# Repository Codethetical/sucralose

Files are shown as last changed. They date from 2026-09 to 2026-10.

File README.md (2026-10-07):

# Sucralose

Sucralose is a wireless, 42-key split keyboard built around Kailh PG1316S ultra-low-profile switches.
One reversible PCB serves both halves.

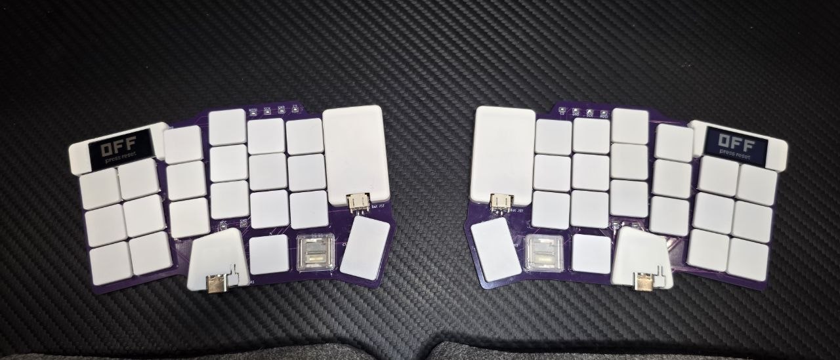
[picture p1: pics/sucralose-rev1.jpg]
Sucralose Rev. 1, both halves assembled


## Hardware

- **Switches:** [Kailh PG1316S](https://www.kailhswitch.com/uploads/15927/files/CPG1316S01D02-data-sheet.pdf),
  21 per half, on a 17 mm pitch to fit their smaller keycaps.
- **Controller:** Seeed XIAO nRF52840 Plus, running [ZMK](https://zmk.dev).
- **Display:** [nice!view](https://nicekeyboards.com/nice-view/), soldered flush to keep the stack low.
- **Power:** a LiPo pouch in a corner bay beside the key field, a JST-PH connector, and a side slide switch.
  An optional side reset button is also supported.
- **PCB:** 1 mm thick, so the full stack stays in ultra-low-profile range.

## Design

- **Layout:** the column splay is inspired by [chalk](https://github.com/maurzo/chalk).
  The 1.5u outer thumb key comes from the [Corne](https://github.com/foostan/crkbd).
- **Reversible:** each half uses the same board, flipped.
  - The XIAO footprint puts a land on both copper layers at every pin.
    Each layer carries the net that pin needs when the module is mounted on that side.
  - The nice!view header can't do that because its pins are plated through-holes.
    Four solder jumpers per side select its pin order instead.
- **Serviceable switches:** the PG1316S contacts sit under the switch body.
  The custom footprint uses plated through-holes so each joint can be reflowed from the underside.

## Custom Footprints

These live in `lib/footprints.pretty/`. The files ending in `_sucralose` were drawn for this board.

- **PG1316S:** a reversible footprint with plated through-holes and locating-pin holes.
  It builds on [mikefive](https://github.com/mikeholscher/zmk-config-mikefive)'s footprints and
  [marbastlib](https://github.com/ebastler/marbastlib)'s.
- **XIAO nRF52840 Plus:** a reversible version of Seeed's official single-sided footprint.
- **nice!view:** a dual-sided header, plus chevron solder jumpers for net selection.
- **Alps SSSS811101 power switch:** front and back versions, checked against
  [ceoloide's footprints](https://github.com/ceoloide/ergogen-footprints).
- **Other parts:** a reversible B3U reset button and SOD-123 diodes.

## Case

`case/out/` has STL files for the partial covers: a battery cover and battery plate, left and right XIAO covers, and a screen cover.
It also has left and right reference DXFs showing the outline, keycap clearances, and M1 screw holes.

## Firmware

This repo is also the [ZMK module](https://zmk.dev/docs/features/modules) for the board: `firmware/` holds the
`sucralose_left` / `sucralose_right` shield. See [`firmware/README.md`](firmware/README.md) for how to build it.

## License

Sucralose is released under the [MIT License](LICENSE).

The key switch layout is the exception. To the extent it is unchanged from [chalk](https://github.com/maurzo/chalk) by maurzo,
that layout stays under chalk's [CC BY-NC-SA 4.0](https://creativecommons.org/licenses/by-nc-sa/4.0/) license.
Third-party files in `reference/` and the footprints derived from upstream libraries also keep their own licenses.

## Credits

- **Corne:** [foostan/crkbd](https://github.com/foostan/crkbd), CC-BY-4.0.
- **Key switch layout:** [maurzo/chalk](https://github.com/maurzo/chalk) by maurzo, CC-BY-NC-SA-4.0.
- **PG1316S footprints:** [mikeholscher/zmk-config-mikefive](https://github.com/mikeholscher/zmk-config-mikefive)
  and [ebastler/marbastlib](https://github.com/ebastler/marbastlib), CERN-OHL-P.
- **PG1316M footprint and 3D model:** [dennisleexyz/libmodulo](https://github.com/dennisleexyz/libmodulo), GPL-3.0.

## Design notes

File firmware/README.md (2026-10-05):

# Sucralose firmware (ZMK module)

This repo is a [ZMK module](https://zmk.dev/docs/features/modules): `zephyr/module.yml` at the
repo root points ZMK at `firmware/`, which holds the `sucralose_left` / `sucralose_right` shield.

- Controller: Seeed XIAO nRF52840 Plus or Sense Plus, built as `seeeduino_xiao_ble`
  (see `docs/PINOUT.md` for why not `xiao_ble_sense`)
- Display: nice!view on both halves
- ZMK: v0.3

## Using it

In your zmk-config's `config/west.yml`, add this repo next to ZMK:

```yaml
    - name: sucralose
      remote: codethetical   # url-base: https://github.com/Codethetical
      revision: main
```

and in `build.yaml`:

```yaml
include:
  - board: seeeduino_xiao_ble
    shield: sucralose_left nice_view
  - board: seeeduino_xiao_ble
    shield: sucralose_right nice_view
```

`nice_view` must come after `sucralose_*`: the shield defines the display bus that `nice_view`
attaches to. There is no `nice_view_adapter`; the display is wired straight to the XIAO.

The left half is the central and advertises as "Sucralose". The default keymap is a 6-column
Corne layout; RESET and BOOT on the raise layer replace the XIAO's button.

## Pins

| Function | XIAO | nRF52840 |
|---|---|---|
| COL0..COL5 | D0 D1 D2 D3 D10 D5 | P0.02 P0.03 P0.28 P0.29 P1.15 P0.05 |
| ROW0..ROW3 | D6..D9 | P1.11..P1.14 |
| Display MOSI / SCK / CS | D4 / D11 / D12 | P0.04 / P0.15 / P0.19 (SPIM3) |

Both XIAO lands carry the same nets, so both halves use the same pins; the right half lists the
columns in reverse because its board is flipped.

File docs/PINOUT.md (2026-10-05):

# XIAO nRF52840 Plus pin assignment

## Where these pin numbers come from

ZMK has no board definition for the **Plus** -- only `seeed/xiao_ble` for the
standard XIAO nRF52840. The Plus keeps the standard 14-pin layout and adds nine
castellated pins, so the mapping was resolved from primary sources and
cross-checked, never from the wiki pinout image (which is disputed -- see below).

| Source | What it establishes |
|---|---|
| Zephyr `boards/seeed/xiao_ble/seeed_xiao_connector.dtsi` | `xiao_d` nexus: D0..D10 -> P0.02 P0.03 P0.28 P0.29 P0.04 P0.05 P1.11 P1.12 P1.13 P1.14 P1.15. ZMK inherits this. |
| Seeed `XIAO_Series_SCH_Symbols` symbol `XIAO-nRF52840_Plus_SMD` | Footprint pad number -> pin name: pads 1..11 = D0..D10, 12=3V3, 13=GND, 14=VBUS, pads 15..23 = D11..D19. |
| Seeed Plus KiCad PCB, header footprint `U4` | Pad -> net. Pads 1..11 match the Zephyr nexus exactly; pads 15..23 give D11..D19. |
| `reference/chalk/reversible.kicad_pcb` | A working board. Its XIAO pads 1..14 are netted P0..P10 / VCC33 / GND / VCC5, agreeing with the symbol on all 14 shared pads. |

Two independent chains agree on every pin used here.

## Full Plus pin table

| Pad | Name | Port | Used for |
|---|---|---|---|
| 1 | D0 | P0.02 | COL0 |
| 2 | D1 | P0.03 | COL1 |
| 3 | D2 | P0.28 | COL2 |
| 4 | D3 | P0.29 | COL3 |
| 5 | D4 | P0.04 | display MOSI |
| 6 | D5 | P0.05 | COL5 |
| 7 | D6 | P1.11 | ROW0 |
| 8 | D7 | P1.12 | ROW1 |
| 9 | D8 | P1.13 | ROW2 |
| 10 | D9 | P1.14 | ROW3 |
| 11 | D10 | P1.15 | COL4 |
| 12 | 3V3 | - | display VCC |
| 13 | GND | - | GND |
| 14 | VBUS | - | (unused) |
| 15 | D11 | P0.15 | display SCK |
| 16 | D12 | P0.19 | display CS |
| 17 | D13 | P1.01 | free |
| 18 | D14 | P0.09 | free (NFC) |
| 19 | D15 | P0.10 | free (NFC) |
| 20 | D16 | P0.31 | free (battery sense) |
| 21 | D17 | P1.03 | free (disputed) |
| 22 | D18 | P1.05 | free (disputed) |
| 23 | D19 | P1.07 | free (disputed) |

## Pins deliberately avoided

- **D14 = P0.09, D15 = P0.10** are NFC pins by default. Usable as GPIO only with
  `CONFIG_NFCT_PINS_AS_GPIOS`.
- **D16 = P0.31** is AIN7/BAT. ZMK's `xiao_ble` board reads battery voltage on
  the ADC, so leave it alone.
- **D17/D18/D19 = P1.03/P1.05/P1.07.** Seeed's published Plus pinout image is
  reported wrong for exactly these: one user found "1.03 and 1.07 are SWAPPED"
  and confirmed it against the KiCad files; another found that blinking D19 lit
  the pad silkscreened D17. Seeed acknowledged an inconsistency. Nothing here
  depends on them.

The whole design fits in **D0..D12**, all corroborated by two independent
sources, leaving D13..D19 free.

## ZMK kscan

`diode-direction = "col2row"`: current flows column -> switch -> diode anode ->
cathode -> row, which is how the netlist is wired (switch pad 1 = column,
switch pad 2 = diode pad 2, diode pad 1 = row).

```dts
kscan0: kscan {
    compatible = "zmk,kscan-gpio-matrix";
    wakeup-source;
    diode-direction = "col2row";

    col-gpios
        = <&xiao_d 0 GPIO_ACTIVE_HIGH>   /* COL0  D0  P0.02 */
        , <&xiao_d 1 GPIO_ACTIVE_HIGH>   /* COL1  D1  P0.03 */
        , <&xiao_d 2 GPIO_ACTIVE_HIGH>   /* COL2  D2  P0.28 */
        , <&xiao_d 3 GPIO_ACTIVE_HIGH>   /* COL3  D3  P0.29 */
        , <&xiao_d 10 GPIO_ACTIVE_HIGH>  /* COL4  D10 P1.15 */
        , <&xiao_d 5 GPIO_ACTIVE_HIGH>   /* COL5  D5  P0.05 */
        ;

    row-gpios
        = <&xiao_d 6 (GPIO_ACTIVE_HIGH | GPIO_PULL_DOWN)>  /* ROW0 D6 P1.11 */
        , <&xiao_d 7 (GPIO_ACTIVE_HIGH | GPIO_PULL_DOWN)>  /* ROW1 D7 P1.12 */
        , <&xiao_d 8 (GPIO_ACTIVE_HIGH | GPIO_PULL_DOWN)>  /* ROW2 D8 P1.13 */
        , <&xiao_d 9 (GPIO_ACTIVE_HIGH | GPIO_PULL_DOWN)>  /* ROW3 D9 P1.14 */
        ;
};
```

The `xiao_d` nexus only defines D0..D10. Display lines (as shipped in
`firmware/boards/shields/sucralose/boards/seeeduino_xiao_ble.overlay`):

```dts
&pinctrl {
    spi3_default: spi3_default {
        group1 {
            psels = <NRF_PSEL(SPIM_SCK,  0, 15)>,   /* SCK  D11 P0.15 */
                    <NRF_PSEL(SPIM_MOSI, 0, 4)>;    /* MOSI D4  P0.04 */
        };
    };
    /* spi3_sleep: same pins, low-power-enable */
};
nice_view_spi: &spi3 {
    compatible = "nordic,nrf-spim";
    pinctrl-0 = <&spi3_default>;
    pinctrl-1 = <&spi3_sleep>;
    pinctrl-names = "default", "sleep";
    cs-gpios = <&gpio0 19 GPIO_ACTIVE_HIGH>;         /* CS   D12 P0.19 */
};
```

SCK, MOSI and CS all sit on pins the nRF52840 spec rates for a fast clock
(table below). No MISO: the LS0xx is write-only.

- **CS is active high.** The LS0xx selects on a high SCS, and ZMK's own
  nice!view adapters use `GPIO_ACTIVE_HIGH`. Active low leaves the panel blank.
- **Why SPIM3.** On the `seeeduino_xiao_ble` board ZMK builds for, spi2 and
  i2c0 are defined but disabled, so SPIM0..3 are all free. SPIM0 is avoided
  because it shares its peripheral with TWIM0, the I2C bus the Sense's
  on-module IMU uses (P0.07/P0.27); SPIM3 keeps that open.
- **Board choice.** Build as `seeeduino_xiao_ble`, not Zephyr's `xiao_ble_sense`.
  The latter enables i2c1 on D4/D5 (display MOSI, COL5), spi2 on D8..D10
  (ROW2, ROW3, COL4) and uart0 on D6/D7 (ROW0, ROW1), and has no ZMK battery
  or USB/BLE config. The Sense's IMU and microphone sit on internal pins, so
  this board choice does not rule them out.

## Matrix

21 keys: 6 columns x 3 rows, plus 3 thumbs on ROW3.

| | COL0 outer | COL1 pinky | COL2 ring | COL3 middle | COL4 index | COL5 inner |
|---|---|---|---|---|---|---|
| ROW0 | SW13 | SW16 | SW3 | SW14 | SW9 | SW6 |
| ROW1 | SW5 | SW20 | SW7 | SW10 | SW12 | SW11 |
| ROW2 | SW19 | SW1 | SW8 | SW18 | SW2 | SW15 |
| ROW3 | - | - | - | SW4 | SW21 | SW17 |

## Display SPI pins: which GPIOs can carry a 1 MHz clock

Source: nRF52840 Product Specification v1.11, section 7 "aQFN73 ball
assignments" (pages 926–933 of the DigiKey PDF). Each GPIO is tagged either
plain "General purpose I/O" or "Standard drive, low frequency I/O only".
Nordic defines low frequency as up to 10 kHz (note on the same table;
DevZone case 232044 confirms: the tag marks pins near the radio that can
desense it when driven fast). The nice!view runs at `spi-max-frequency =
<1000000>` (ZMK `shields/nice_view/nice_view.overlay`), 100x over that.

| Pad | Name | Port | Spec tag | 1 MHz SPI |
|---|---|---|---|---|
| 1 | D0 | P0.02 | low frequency only | no |
| 2 | D1 | P0.03 | low frequency only | no |
| 3 | D2 | P0.28 | low frequency only | no |
| 4 | D3 | P0.29 | low frequency only | no |
| 5 | D4 | P0.04 | general purpose | **yes** |
| 6 | D5 | P0.05 | general purpose | **yes** |
| 7 | D6 | P1.11 | low frequency only | no |
| 8 | D7 | P1.12 | low frequency only | no |
| 9 | D8 | P1.13 | low frequency only | no |
| 10 | D9 | P1.14 | low frequency only | no |
| 11 | D10 | P1.15 | low frequency only | no |
| 15 | D11 | P0.15 | general purpose | **yes** |
| 16 | D12 | P0.19 | general purpose (QSPI/SCK on the module) | **yes** |
| 17 | D13 | P1.01 | low frequency only | no |
| 18 | D14 | P0.09 | low frequency only, NFC | no |
| 19 | D15 | P0.10 | low frequency only, NFC | no |
| 20 | D16 | P0.31 | low frequency only, battery sense | no |
| 21 | D17 | P1.03 | low frequency only | no |
| 22 | D18 | P1.05 | low frequency only | no |
| 23 | D19 | P1.07 | low frequency only | no |

Consequences:

- The current SCK/CS on D11/D12 (pads 15/16) are the right *electrical*
  choice: they are two of only four pins on the whole module rated for a
  fast clock. They are also the two hardest pads to route.
- Of the Plus-only pins, none is rated for SPI. Moving SCK or CS to
  D13–D19 to ease routing would put the display clock on a radio-adjacent
  pin the spec limits to 10 kHz. Seeed's own board uses P1.13/P1.15
  (low-frequency pins) for its stock `spi2`, so it works in practice, but
  it is out of spec with the radio on.
- The only in-spec fast pins on the **non-Plus** XIAO edge are D4 and D5
  (P0.04/P0.05). A design that must run on the original XIAO nRF52840 has
  exactly two SPI-capable pins, which is SCK + MOSI with CS on any GPIO
  (CS is static, no frequency limit). That leaves 9 pins for the matrix:
  a 6x4 needs 10. So the non-Plus board cannot carry this matrix plus an
  in-spec display; the Plus is required, and D11/D12 stay.
- MOSI was on D10 (P1.15), a low-frequency pin, carrying data at the same
  1 MHz as SCK. Decided 2026-09-19: MOSI moved to D4 (P0.04, fast pin);
  COL4 took D10. Matrix scanning is far below 10 kHz, so a column on a
  low-frequency pin is in spec. All three display lines (MOSI D4, SCK D11,
  CS D12) are now on the four fast pins.

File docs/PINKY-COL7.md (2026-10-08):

# Pinky Column 7 (Branch `pinky-col7`): Status and Handoff

Last updated 2026-10-07 (UTC). Head `1fa790a`. Main is untouched.

## What Exists

- **Footprint:** `lib/footprints.pretty/SW_PG1316M_th_reversible_sucralose.kicad_mod` (on main, GPL-3.0, derived from dennisleexyz/libmodulo `SW_PG1316M` @5dbcd9b). The datasheet's 1.55x2 mm terminal lands at (+/-2.5, 0.7) are PTH with a 1.0 mm drill. The MP pads at (+/-6.35, +/-3.95) are duplicated F/B. Locating NPTHs at (+/-5.8, 0) are both 1.25 mm so either face fits. Courtyard is 16x10.3 mm (F-row keycap); the case guard is +0.5 mm, about 17.0x11.3 mm.
- **Datasheet and model:** `docs/PG1316M-datasheet.pdf`, `lib/3d/PG1316M.STEP`.
- **Strip:** 4x PG1316M, portrait (rot 9-90 = -81), at u=-17.5 in COL0's frame (origin = SW5 `C0 R1`, rot 9 deg), 17 mm pitch, centred in the strip.
  - Refs top to bottom: C6 R3 (D22, ROW3), C6 R0 (D23, ROW0), C6 R1 (D24, ROW1), C6 R2 (D25, ROW2).
  - Switch-to-diode nets: `pinky7_extra/top/home/bottom`.
  - COL6 goes to XIAO pad 17 (D13 = P1.01) on both copies. C6 R3 uses the free ROW3/COL6 matrix slot.
- **Breakaway:**
  - Five tabs of 0.6 mm NPTH perforations with a 0.35 mm web, plus 1.0 mm slots (the JLCPCB minimum NP slot). The fifth (MB5, 5 holes, solid span 5.46 mm) sits at the C6 R0/R1 key boundary and splits the long middle slot.
  - The main-side slot wall lies on the Rev. 1 COL0 edge, so the snapped board keeps the Rev. 1 outline and corners and existing covers fit.
  - The strip spans the full board height, and its outer corners copy the main corner rounds. Inner corners now hug the main board's corner rounds: a 1.0 mm-gap arc concentric with each main corner, filleted R0.5 into the strip's top/bottom edge (`scripts/hug_pinky_col7_corners.py`, run after `gen_pinky_col7.py`).
  - Middle tabs carry the nets (3+3 holes around a copper channel). Dead-end stubs remain after a snap; file the edge.
- **DRC:** copper clean. The unconnected set matches main (7 display/battery ring pairs). Only new items are 8 `lib_footprint_issues` local-override warnings.

## Open Items

1. **ROW3 trace:** C6 R3's ROW3 trace runs diagonally across the C0 R0/R1 area on the top side. It's cosmetic. Jahn was offered a reroute along the edge or under the display; no decision yet.
2. **Firmware not updated:**
   - 7 columns: add COL6 = `&xiao_d 13` to the left/right overlays (the right is mirrored, so COL6 goes first) and `col-offset` = 7.
   - Matrix transform and keymap need the C6 positions (R0-R3).
3. **Keycap gap:** C6 keycaps sit about 4.3 mm from C0's; main columns are about 1 mm apart. Closing it pushes the switches into the slots.
4. **Not done yet:** cover/case model updates, a JLCPCB order check (confirm mouse bites and slots in the Gerber preview), and a physical snap test.

## How It Was Built (Scripts Are Gitignored, Local Only)

- `scripts/gen_pinky_col7.py`: start from `git show main:pcb/sucralose.kicad_pcb`. It places the switches, diodes, and mouse bites, rewrites the COL0 edge, and adds pad-17 COL6. It snaps new outline ends to existing ones and drops zero-length lines (KiCad `invalid_outline` otherwise).
- `scripts/route/route_col7.py`: run `extract_geom.py` first. It freezes existing copper, routes only the strip nets, and ties the diode back lands with vias. Takes about 1 minute.
- To verify: run DRC against `main` (`kicad-cli pcb drc`) and diff the category counts.

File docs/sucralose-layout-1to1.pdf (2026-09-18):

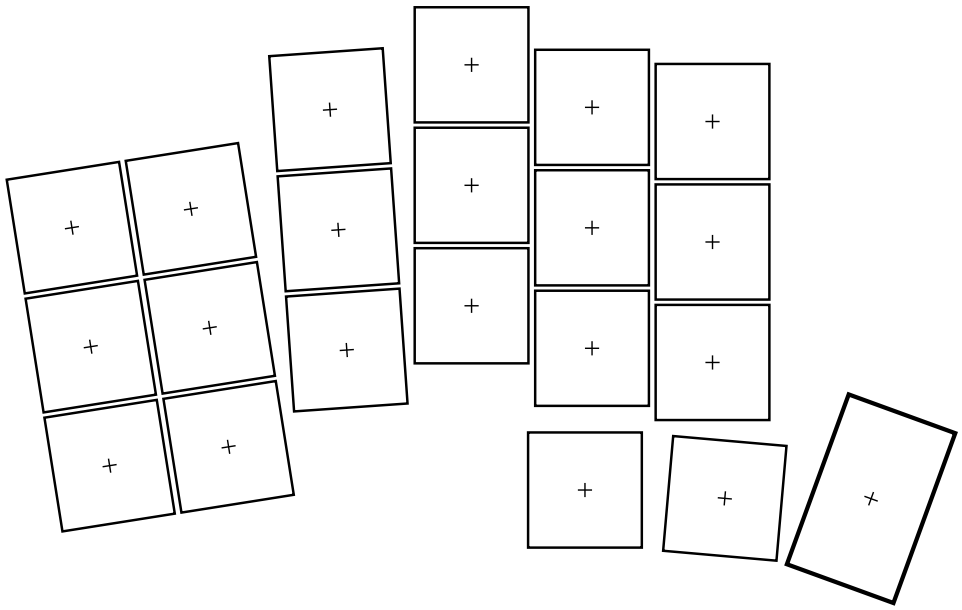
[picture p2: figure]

VERIFY SCALE FIRST: this ruler must measure exactly 100 mm. Print at 100%, scaling OFF / "Actual size".

SUCRALOSE · LEFT half · chalk splay, 17 mm pitch · outer thumb 1.5u (25.5 x 16 mm), rotated +90 deg, raised 4.8 mm

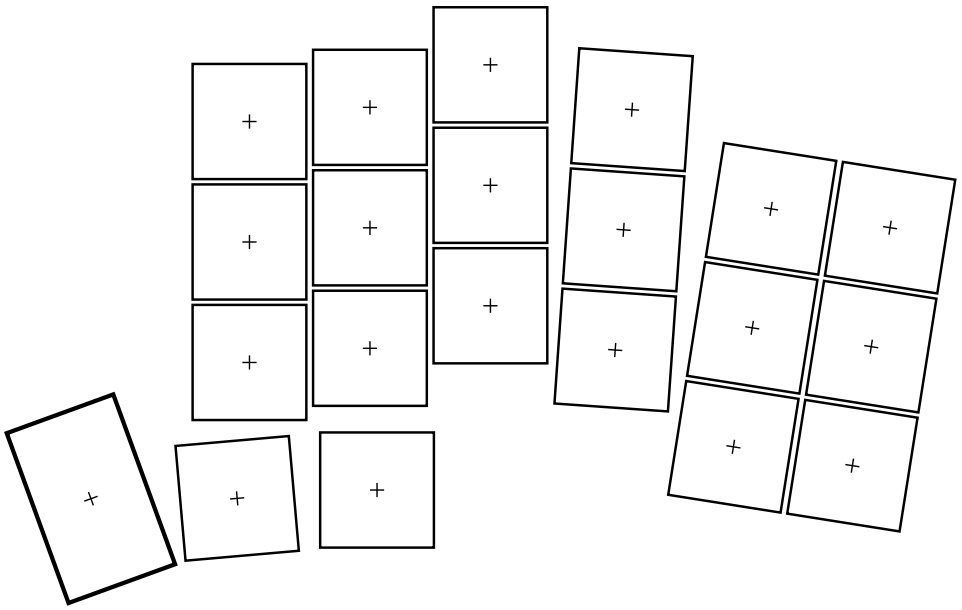
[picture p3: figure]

VERIFY SCALE FIRST: this ruler must measure exactly 100 mm. Print at 100%, scaling OFF / "Actual size".

SUCRALOSE · RIGHT half · chalk splay, 17 mm pitch · outer thumb 1.5u (25.5 x 16 mm), rotated +90 deg, raised 4.8 mm

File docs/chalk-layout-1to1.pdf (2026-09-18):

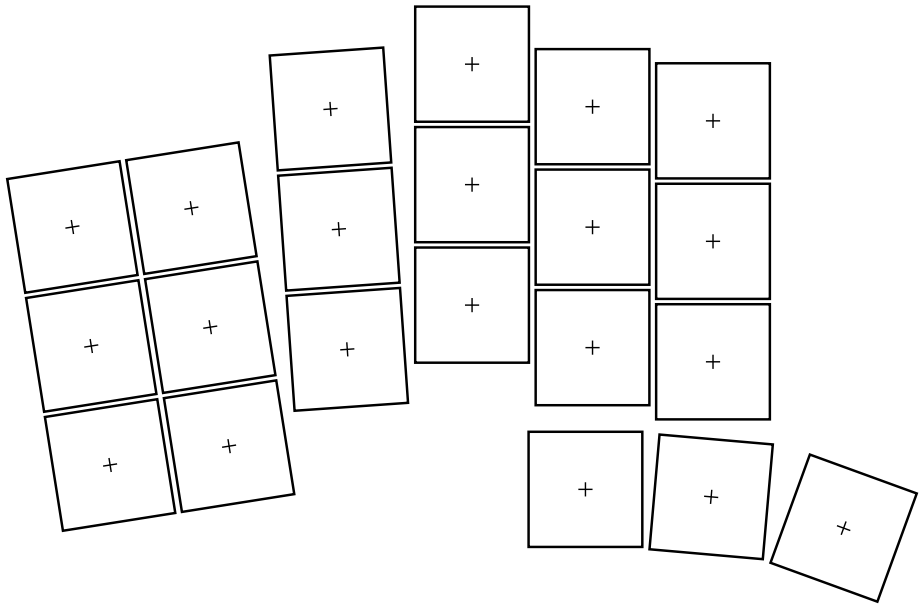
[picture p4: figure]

VERIFY SCALE FIRST: this ruler must measure exactly 100 mm. Print at 100%, scaling OFF / "Actual size".

LEFT half · chalk layout, 17 mm pitch, PG1316S 1u caps 16.05 x 16.25 mm · geometry measured from maurzo/chalk (CC-BY-NC-SA-4.0)

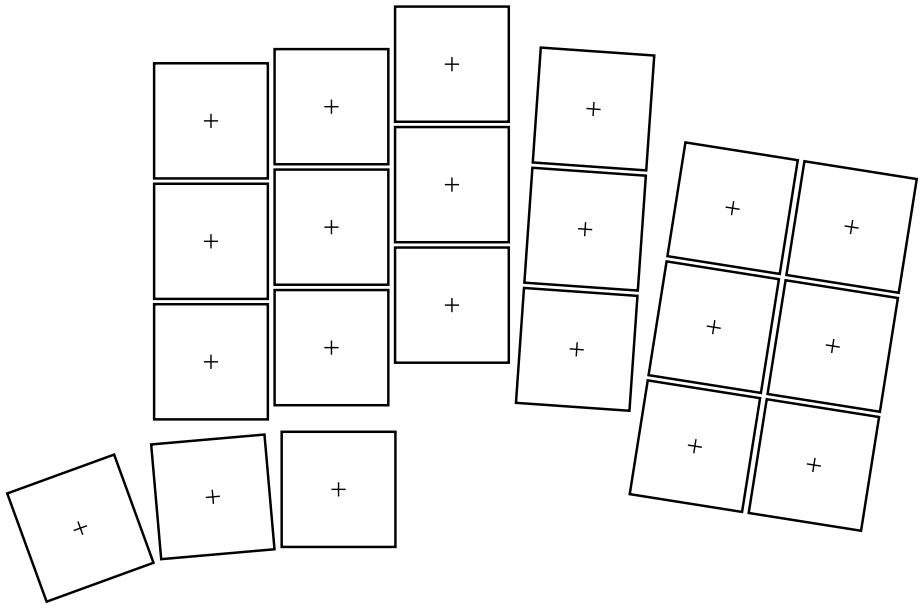
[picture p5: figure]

VERIFY SCALE FIRST: this ruler must measure exactly 100 mm. Print at 100%, scaling OFF / "Actual size".

RIGHT half · chalk layout, 17 mm pitch, PG1316S 1u caps 16.05 x 16.25 mm · geometry measured from maurzo/chalk (CC-BY-NC-SA-4.0)

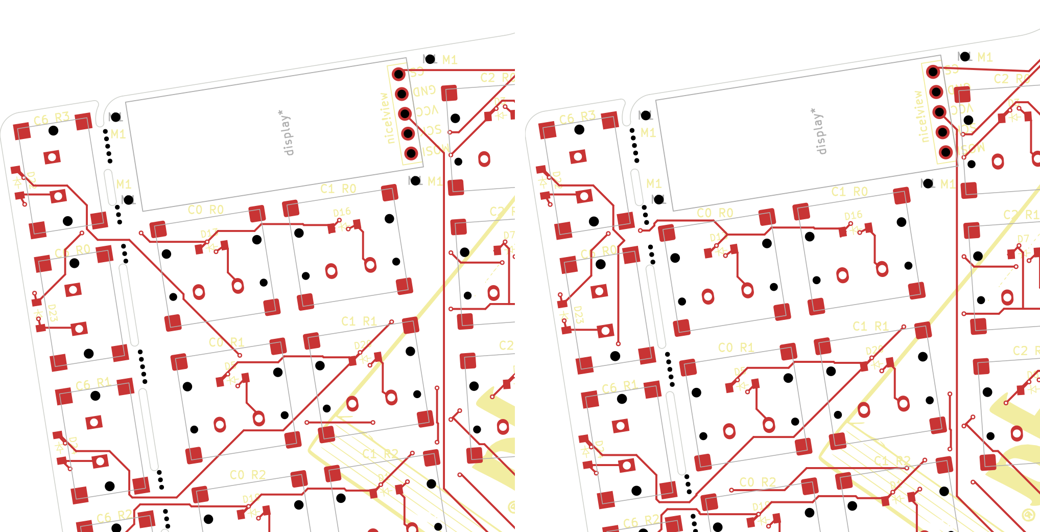
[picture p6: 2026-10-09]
pics/sucralose-display-inboard-compare.png

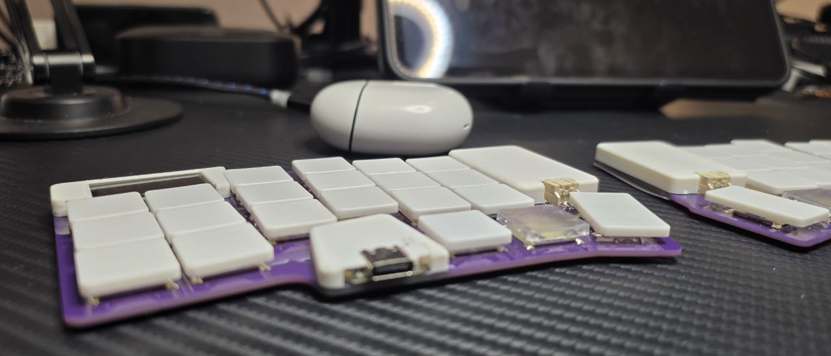
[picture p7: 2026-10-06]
pics/rev1-front-angled.jpg

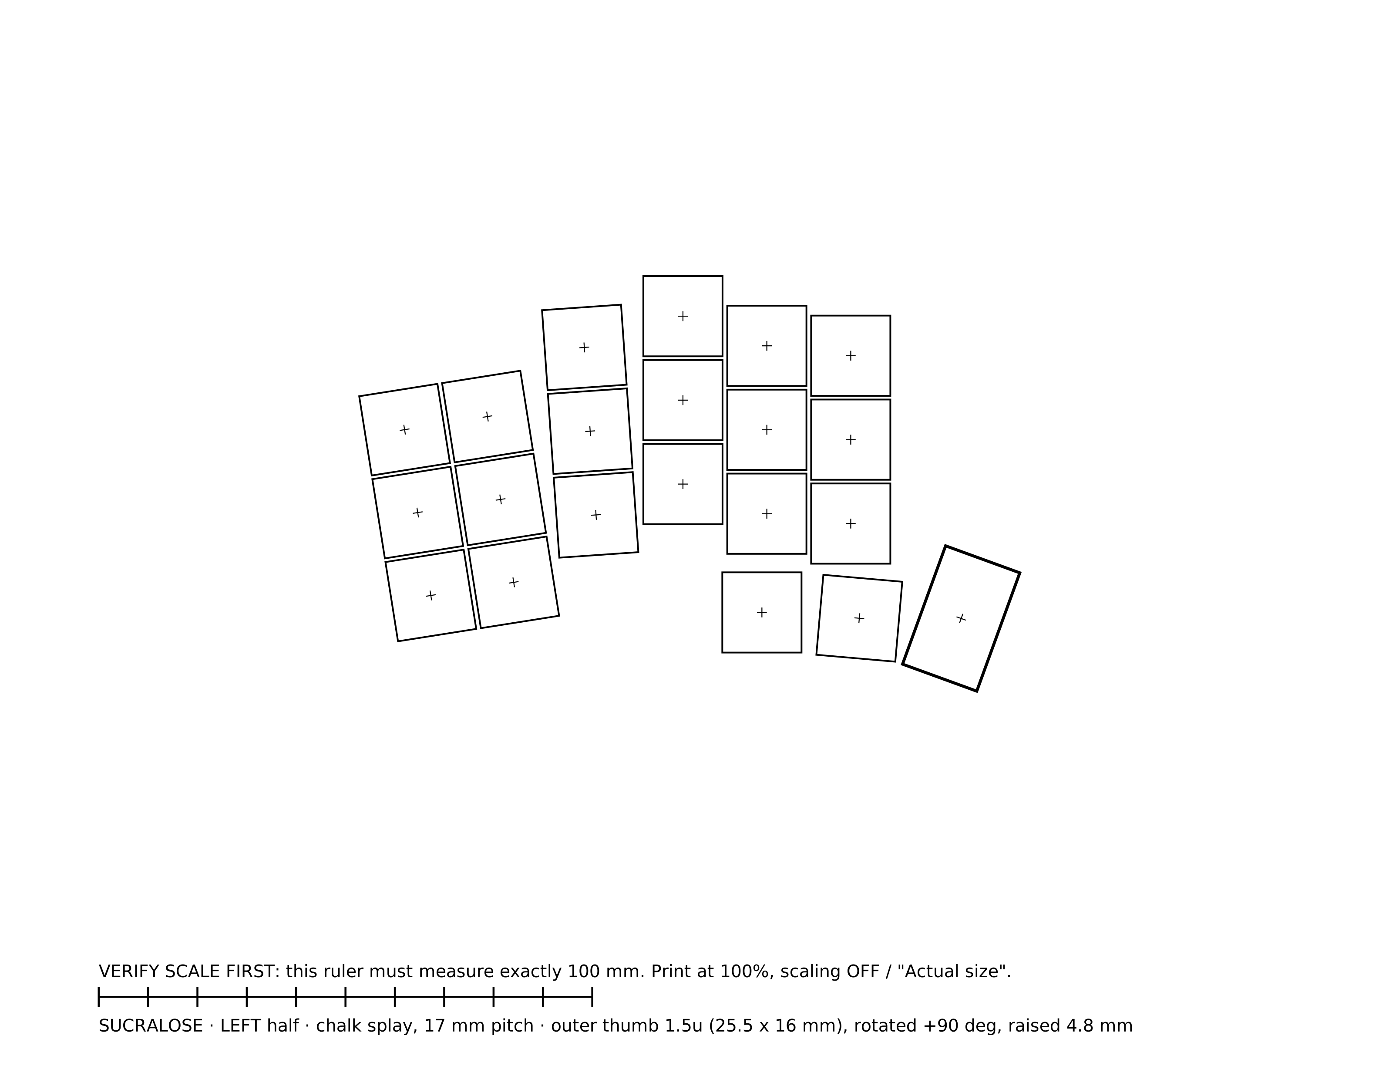
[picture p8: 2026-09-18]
docs/img/sucralose-layout-left.png

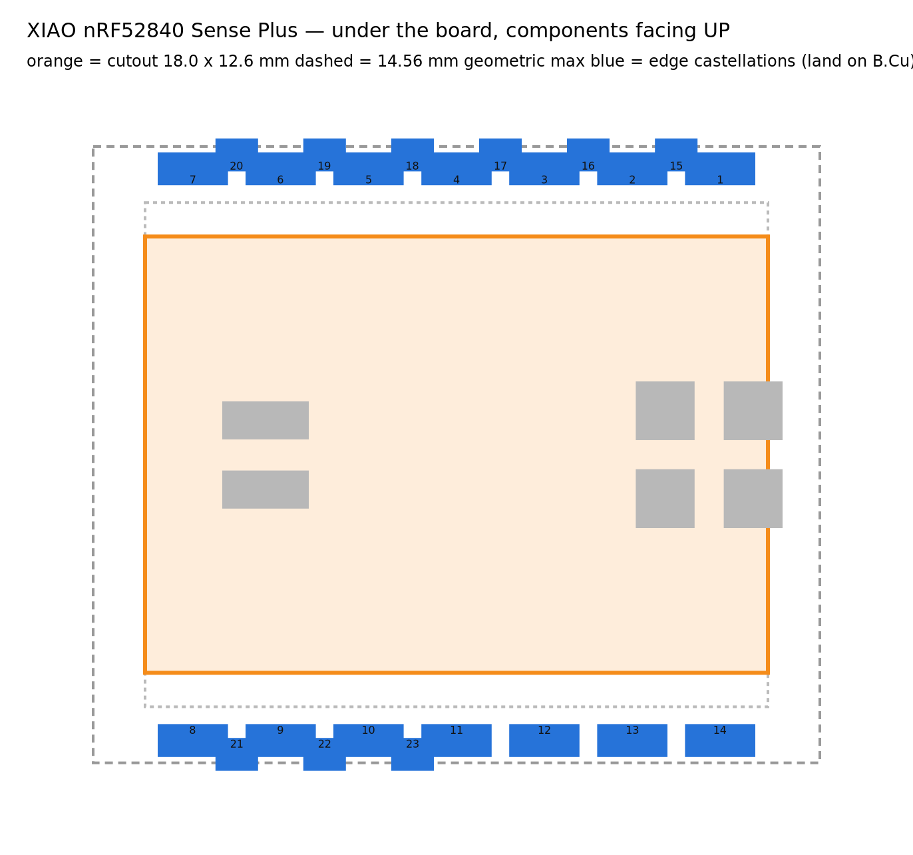
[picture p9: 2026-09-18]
docs/img/xiao-cutout.png

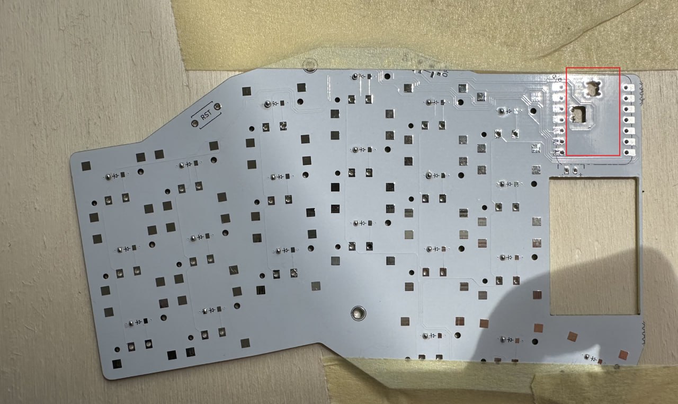
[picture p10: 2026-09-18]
docs/img/chalk-pcb-cutout-reference.jpg

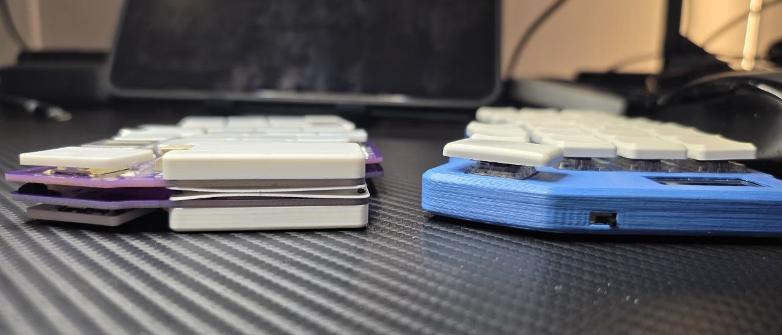
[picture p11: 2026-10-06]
pics/rev1-height-vs-cased-board.jpg

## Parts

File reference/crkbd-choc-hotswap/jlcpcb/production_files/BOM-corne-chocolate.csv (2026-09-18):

Comment | Designator | Footprint | LCSC
W25Q128JVSIQ | U4,rU4 | SOIC-8_5.23x5.23mm_P1.27mm | C113767
1k | R3,R6,rR3,rR6 | R_0402_1005Metric | C11702
TRS | J2,rJ2 | PJ-398A-5A_PJ-399B-6A | C128994
TPD4E05U06DQAR | U3,rU3 | USON-10_2.5x1.0mm_P0.5mm | C138714
RB521S30T1G | ZD1,rZD1 | D_SOD-523 | C145179
NCP1117LPST33T3G | U2,rU2 | SOT-223-3_TabPin2 | C146799
100n | C10,C12,C13,C14,C15,C3,C4,C7,C9,rC10,rC12,rC13,rC14,rC15,rC3,rC4,rC7,rC9 | C_0402_1005Metric | C1525
10u | C11,C6,rC11,rC6 | C_0402_1005Metric | C15525
27p | C1,C2,rC1,rC2 | C_0402_1005Metric | C1557
RP2040 | U1,rU1 | QFN-56-1EP_7x7mm_P0.4mm_EP3.2x3.2mm | C2040
1N4148WT | D1,rD1 | D_SOD-523 | C232841
10k | R7,R9,rR7,rR9 | R_0402_1005Metric | C25744
5.1k | R1,R2,rR1,rR2 | R_0402_1005Metric | C25905
5.6k | R8,rR8 | R_0402_1005Metric | C25908
TYPE-C-31-M-13C | J1,rJ1 | TYPE-C-31-M-13C | C2848620
27 | R4,R5,rR4,rR5 | R_0402_1005Metric | C2909343
TS-1088R-02026 | SMDSW1,SMDSW2,rSMDSW1,rSMDSW2 | TS-1088R-02026 | C455280
YS-SK6812MINI-E | EXLED1,EXLED2,LED1,LED10,LED11,LED12,LED13,LED14,LED15,LED16,LED17,LED18,LED19,LED2,LED20,LED21,LED3,LED4,LED5,LED6,LED7,LED8,LED9,rEXLED1,rEXLED2,rLED1,rLED10,rLED11,rLED12,rLED13,rLED14,rLED15,rLED16,rLED17,rLED18,rLED19,rLED2,rLED20,rLED21,rLED3,rLED4,rLED5,rLED6,rLED7,rLED8,rLED9 | YS-SK6812MINI-E | C5149201
1u | C16,C5,C8,rC16,rC5,rC8 | C_0402_1005Metric | C52923
RotaryEncoder_Switch | EXSW1,EXSW2,SW1,SW10,SW11,SW12,SW13,SW14,SW15,SW16,SW17,SW18,SW19,SW2,SW20,SW21,SW3,SW4,SW5,SW6,SW7,SW8,SW9,rEXSW1,rEXSW2,rSW1,rSW10,rSW11,rSW12,rSW13,rSW14,rSW15,rSW16,rSW17,rSW18,rSW19,rSW2,rSW20,rSW21,rSW3,rSW4,rSW5,rSW6,rSW7,rSW8,rSW9 | keyswitch_choc12_hotswap_1u_rotary_encoder_ec12 | C5333465
12MHz 18pF | Y1,rY1 | Crystal_SMD_3225-4Pin_3.2x2.5mm | C91749

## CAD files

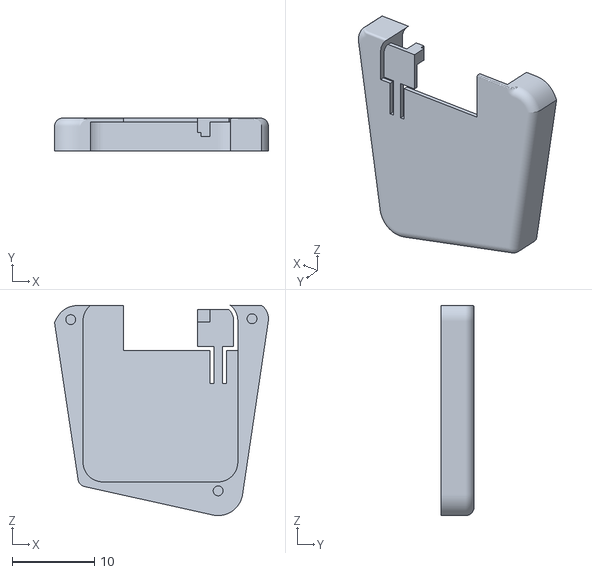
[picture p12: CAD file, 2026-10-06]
case/out/Sucralose L Xiao Cover Rev 4.stl
26.0 x 4.00 x 25.5

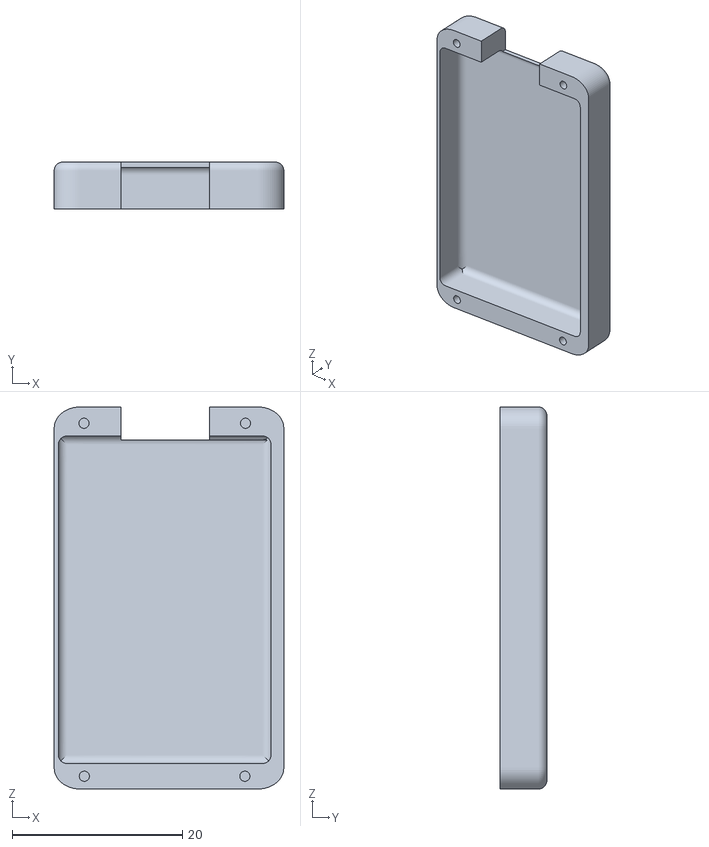
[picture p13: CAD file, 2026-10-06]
case/out/Sucralose L Battery Cover Rev 1.stl
27.0 x 5.50 x 44.9

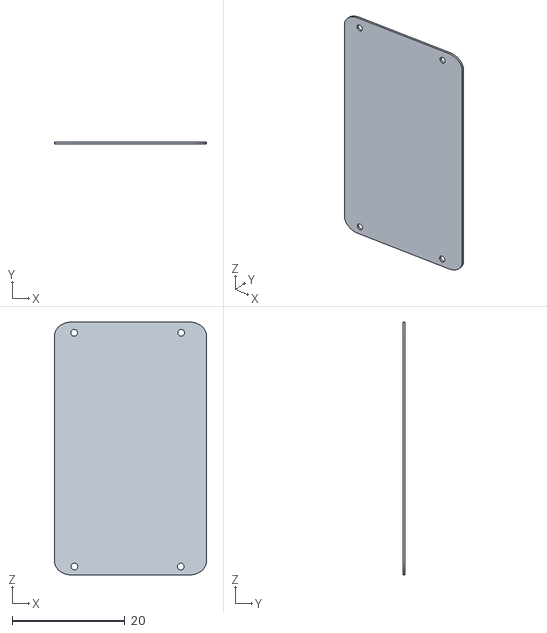
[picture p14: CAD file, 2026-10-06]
case/out/Sucralose L Battery Plate Rev 1.stl
27.0 x 0.4 x 44.9

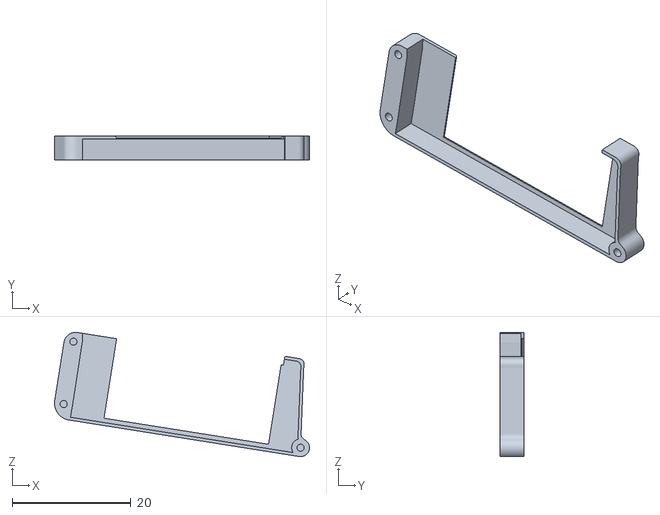
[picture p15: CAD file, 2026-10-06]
case/out/Sucralose L Screen Cover Rev 8.stl
42.9 x 4.00 x 20.9

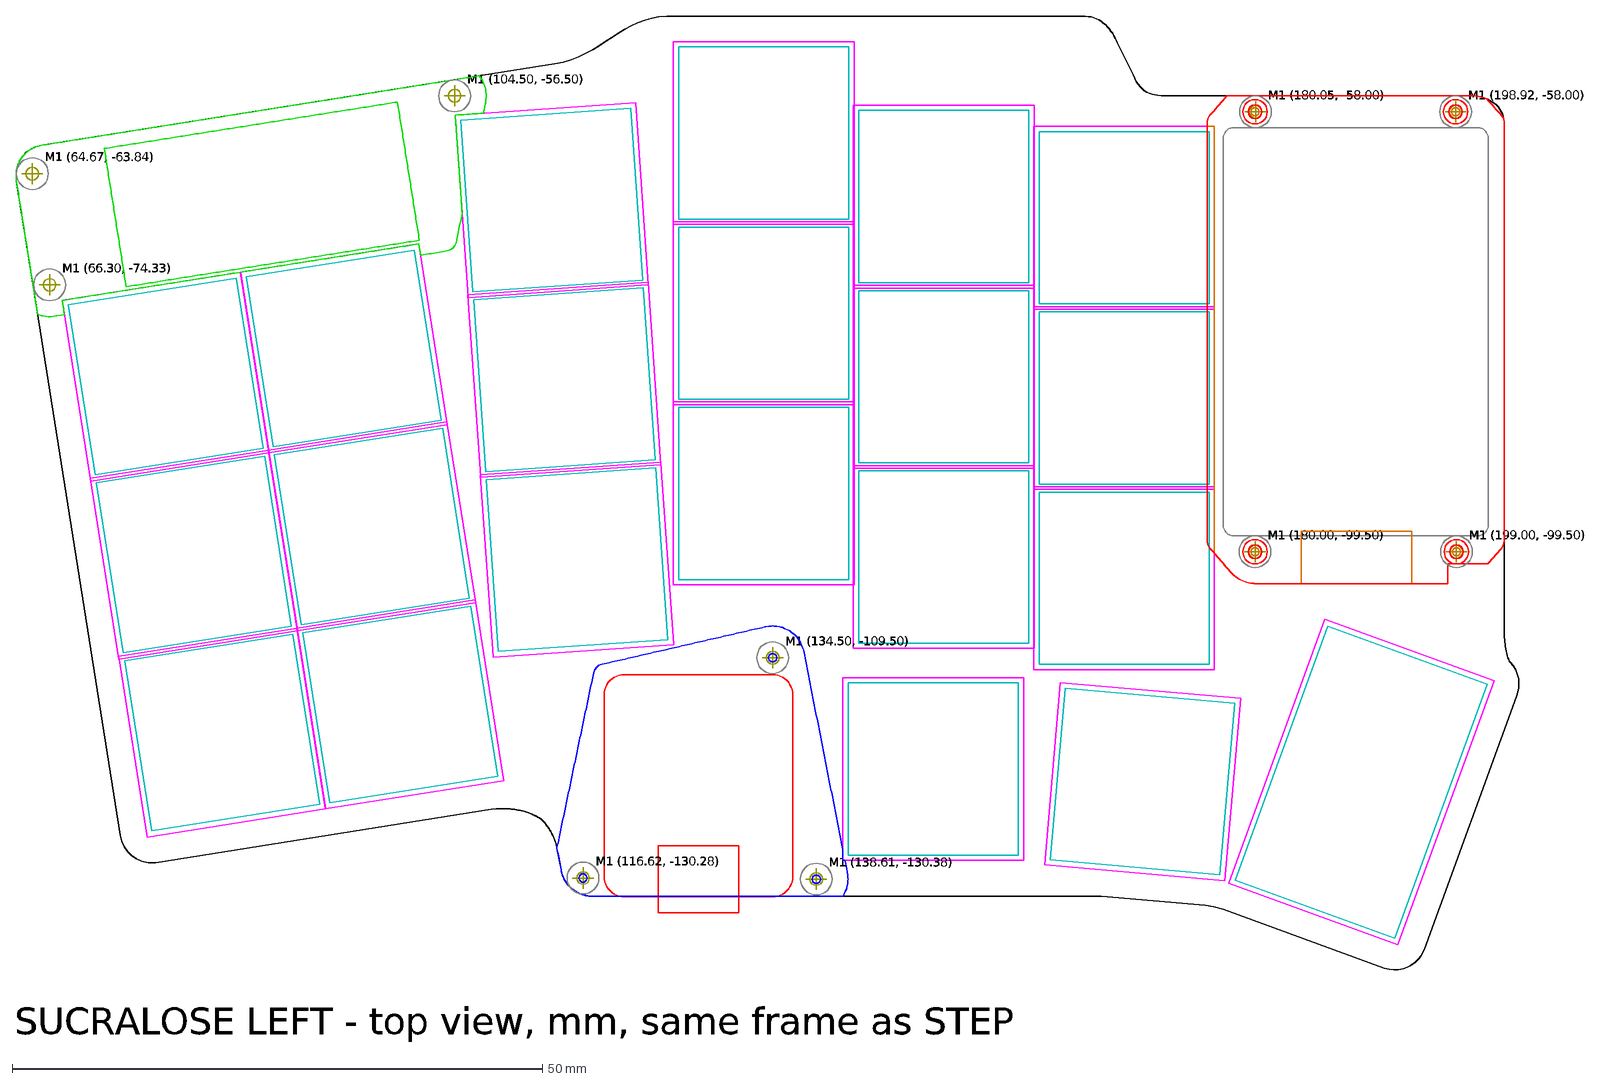
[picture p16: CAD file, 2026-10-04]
case/out/sucralose_reference_L.dxf
M1 (138.61, -130.38)
M1 (199.00, -99.50)
M1 (180.00, -99.50)
M1 (104.50, -56.50)
M1 (198.92, -58.00)
M1 (66.30, -74.33)
M1 (134.50, -109.50)
M1 (116.62, -130.28)
M1 (64.67, -63.84)
M1 (180.05, -58.00)
SUCRALOSE LEFT - top view, mm, same frame as STEP

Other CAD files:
case/out/Sucralose R Xiao Cover Rev 1.stl
case/out/sucralose_reference_R.dxf

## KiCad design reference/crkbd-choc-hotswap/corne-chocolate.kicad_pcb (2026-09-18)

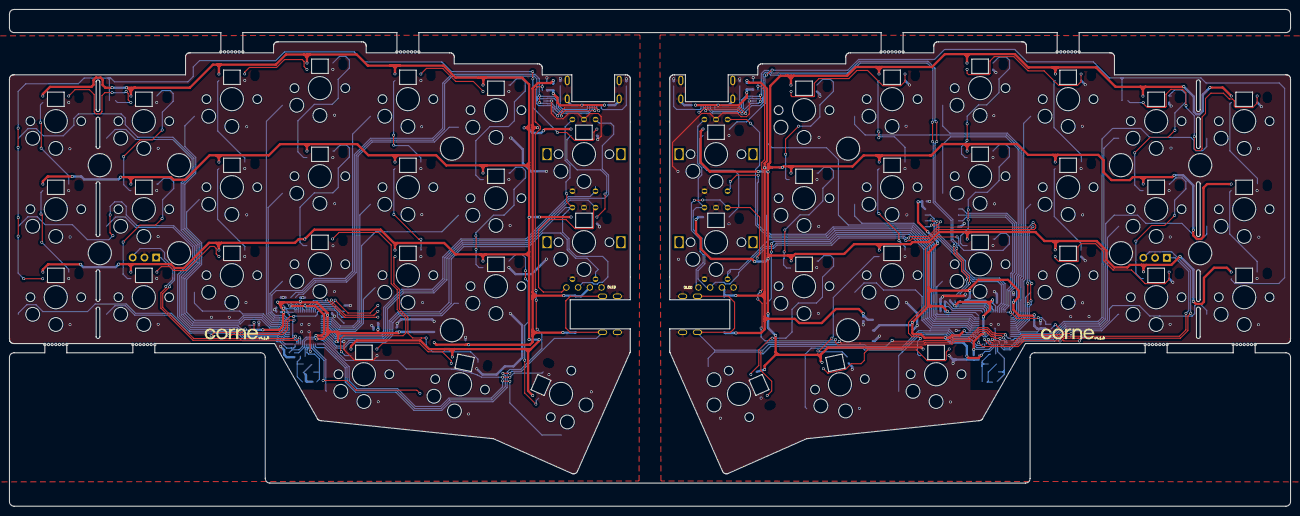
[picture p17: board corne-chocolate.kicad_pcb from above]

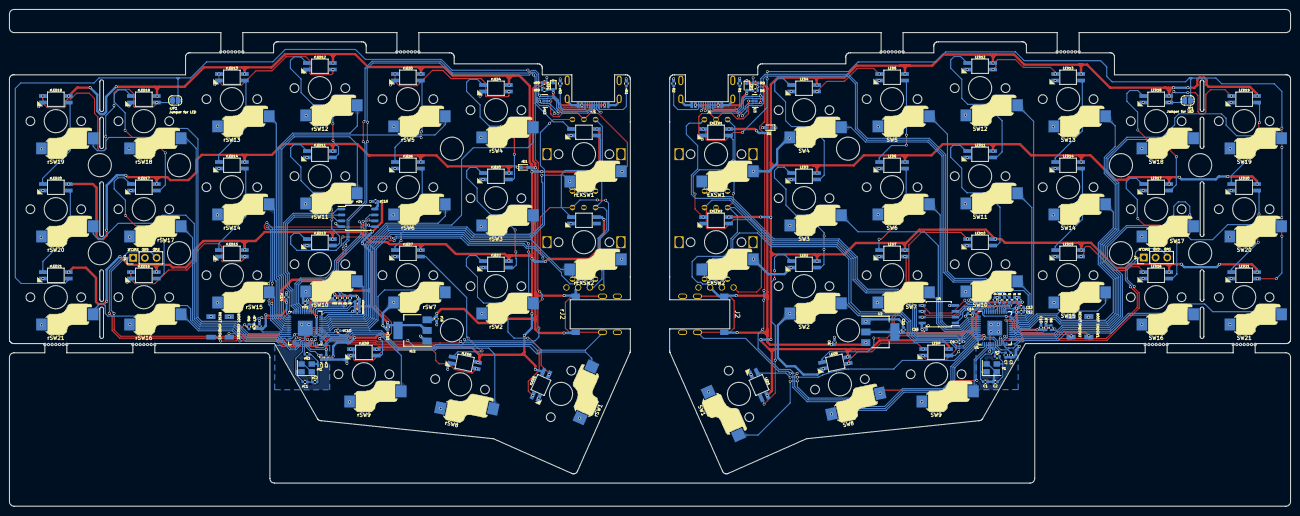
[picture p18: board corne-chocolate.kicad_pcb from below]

Board: 2 copper layers, 277.2 x 107.5 mm, 178 parts (168 on the bottom side), 152 nets.

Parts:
BT1, BT2, BT3, BT4: Breakaway Tabs; Breakaway_Tabs
C1, C2: 27p; C_0402_1005Metric
C3, C4, C7, C9, C10, C12, C13, C14, C15: 100n; C_0402_1005Metric
C5, C8, C16: 1u; C_0402_1005Metric
C6, C11: 10u; C_0402_1005Metric
D1: 1N4148WT; D_SOD-523
EXLED1, EXLED2: YS-SK6812MINI-E
EXSW1, EXSW2: RotaryEncoder_Switch; keyswitch_choc12_hotswap_1u_rotary_encoder_ec12
J1: TYPE-C-31-M-13C
J2: TRS; PJ-398A-5A_PJ-399B-6A
J3: Conn_01x04; OLED
J4: Conn_01x03; PinHeader_1x03_P2.54mm_Vertical
JP1: SolderJumper_2_Bridged; SolderJumper-2_P1.3mm_Open_RoundedPad1.0x1.5mm
LED1, LED2, LED3, LED4, LED5, LED6, LED7, LED8, LED9, LED10, LED11, LED12, LED13, LED14, LED15, LED16, LED17, LED18, LED19, LED20, LED21: YS-SK6812MINI-E
R1, R2: 5.1k; R_0402_1005Metric
R3, R6: 1k; R_0402_1005Metric
R4, R5: 27; R_0402_1005Metric
R7: 10k; R_0402_1005Metric
R8: 5.6k; R_0402_1005Metric
R9: 10K; R_0402_1005Metric
SMDSW1, SMDSW2: TS-1088R-02026
SW1: SW_Push; keyswitch_choc12_hotswap_1.5u
SW2, SW3, SW4, SW5, SW6, SW7, SW8, SW9, SW10, SW11, SW12, SW13, SW14, SW15, SW16, SW17, SW18, SW19, SW20, SW21: SW_Push; keyswitch_choc12_hotswap_1u
U1: RP2040; QFN-56-1EP_7x7mm_P0.4mm_EP3.2x3.2mm
U2: NCP1117LPST33T3G; SOT-223-3_TabPin2
U3: TPD4E05U06DQAR; USON-10_2.5x1.0mm_P0.5mm
U4: W25Q128JVSIQ; SOIC-8_5.23x5.23mm_P1.27mm
Y1: 12MHz 18pF; Crystal_SMD_3225-4Pin_3.2x2.5mm
ZD1: RB521S30T1G; D_SOD-523
rBT1, rBT2, rBT3, rBT4: Breakaway Tabs; Breakaway_Tabs
rC1, rC2: 27p; C_0402_1005Metric
rC3, rC4, rC7, rC9, rC10, rC12, rC13, rC14, rC15: 100n; C_0402_1005Metric
rC5, rC8, rC16: 1u; C_0402_1005Metric
rC6, rC11: 10u; C_0402_1005Metric
rD1: 1N4148WT; D_SOD-523
rEXLED1, rEXLED2: YS-SK6812MINI-E
rEXSW1, rEXSW2: RotaryEncoder_Switch; keyswitch_choc12_hotswap_1u_rotary_encoder_ec12
rJ1: TYPE-C-31-M-13C
rJ2: TRS; PJ-398A-5A_PJ-399B-6A
rJ3: Conn_01x04; OLED
rJ4: Conn_01x03; PinHeader_1x03_P2.54mm_Vertical
rJP1: SolderJumper_2_Bridged; SolderJumper-2_P1.3mm_Open_RoundedPad1.0x1.5mm
rLED1, rLED2, rLED3, rLED4, rLED5, rLED6, rLED7, rLED8, rLED9, rLED10, rLED11, rLED12, rLED13, rLED14, rLED15, rLED16, rLED17, rLED18, rLED19, rLED20, rLED21: YS-SK6812MINI-E
rR1, rR2: 5.1k; R_0402_1005Metric
rR3, rR6: 1k; R_0402_1005Metric
rR4, rR5: 27; R_0402_1005Metric
rR7: 10k; R_0402_1005Metric
rR8: 5.6k; R_0402_1005Metric
rR9: 10K; R_0402_1005Metric
rSMDSW1, rSMDSW2: TS-1088R-02026
rSW1: SW_Push; keyswitch_choc12_hotswap_1.5u
rSW2, rSW3, rSW4, rSW5, rSW6, rSW7, rSW8, rSW9, rSW10, rSW11, rSW12, rSW13, rSW14, rSW15, rSW16, rSW17, rSW18, rSW19, rSW20, rSW21: SW_Push; keyswitch_choc12_hotswap_1u
rU1: RP2040; QFN-56-1EP_7x7mm_P0.4mm_EP3.2x3.2mm
rU2: NCP1117LPST33T3G; SOT-223-3_TabPin2
rU3: TPD4E05U06DQAR; USON-10_2.5x1.0mm_P0.5mm
rU4: W25Q128JVSIQ; SOIC-8_5.23x5.23mm_P1.27mm
rY1: 12MHz 18pF; Crystal_SMD_3225-4Pin_3.2x2.5mm
rZD1: RB521S30T1G; D_SOD-523

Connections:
+1V1: C3.1, C4.1, C5.1, U1.23 (DVDD), U1.45 (VREG_VOUT), U1.50 (DVDD)
+1V1R: rC3.1, rC4.1, rC5.1, rU1.23 (DVDD), rU1.45 (VREG_VOUT), rU1.50 (DVDD)
+3V3: C7.1, C8.1, C9.1, C10.1, C11.1, C12.1, C13.1, C14.1, C15.1, C16.1, R7.2, U1.1 (IOVDD), U1.10 (IOVDD), U1.22 (IOVDD), U1.32 (GPIO21), U1.33 (IOVDD), U1.42 (IOVDD), U1.43 (ADC_AVDD), U1.44 (VREG_IN), U1.48 (USB_VDD), U1.49 (IOVDD), U2.2 (VO), U4.8 (VCC)
+3V3R: rC7.1, rC8.1, rC9.1, rC10.1, rC11.1, rC12.1, rC13.1, rC14.1, rC15.1, rC16.1, rR7.2, rU1.1 (IOVDD), rU1.10 (IOVDD), rU1.22 (IOVDD), rU1.33 (IOVDD), rU1.42 (IOVDD), rU1.43 (ADC_AVDD), rU1.44 (VREG_IN), rU1.48 (USB_VDD), rU1.49 (IOVDD), rU2.2 (VO), rU4.8 (VCC)
+5V: C6.1, D1.2 (A), J2.T, J3.3, U2.3 (VI), ZD1.1 (K)
+5VR: rC6.1, rD1.2 (A), rJ2.T, rJ3.3, rU2.3 (VI), rZD1.1 (K)
/left/D+: J1.A6 (D+), J1.B6 (D+), R4.1, U3.1 (D1+), U3.4 (D2+), U3.7 (NC), U3.10 (NC)
/left/D-: J1.A7 (D-), J1.B7 (D-), R5.2, U3.2 (D1-), U3.5 (D2-), U3.6 (NC), U3.9 (NC)
/left/KEY1: SW1.1, U1.14 (GPIO11)
/left/KEY2: SW2.1, U1.12 (GPIO9)
/left/KEY3: SW3.1, U1.4 (GPIO2)
/left/KEY4: SW4.1, U1.2 (GPIO0)
/left/KEY5: SW5.1, U1.41 (GPIO29_ADC3)
/left/KEY6: SW6.1, U1.3 (GPIO1)
/left/KEY7: SW7.1, U1.5 (GPIO3)
/left/KEY8: SW8.1, U1.18 (GPIO15)
/left/KEY9: SW9.1, U1.17 (GPIO14)
/left/KEY10: SW10.1, U1.40 (GPIO28_ADC2)
/left/KEY11: SW11.1, U1.39 (GPIO27_ADC1)
/left/KEY12: SW12.1, U1.38 (GPIO26_ADC0)
/left/KEY13: SW13.1, U1.35 (GPIO23)
/left/KEY14: SW14.1, U1.36 (GPIO24)
/left/KEY15: SW15.1, U1.37 (GPIO25)
/left/KEY16: SW16.1, U1.27 (GPIO16)
/left/KEY17: SW17.1, U1.29 (GPIO18)
/left/KEY18: SW18.1, U1.31 (GPIO20)
/left/KEY19: SW19.1, U1.34 (GPIO22)
/left/KEY20: SW20.1, U1.30 (GPIO19)
/left/KEY21: SW21.1, U1.28 (GPIO17)
/left/KEYEX1: EXSW1.S2, U1.6 (GPIO4)
/left/KEYEX2: EXSW2.S2, U1.11 (GPIO8)
/left/LED: LED1.4 (DIN), U1.13 (GPIO10)
/left/QSPI_SCLK: U1.52 (QSPI_SCLK), U4.6 (CLK)
/left/QSPI_SD0: U1.53 (QSPI_SD0), U4.5 (DI(IO0))
/left/QSPI_SD1: U1.55 (QSPI_SD1), U4.2 (DO(IO1))
/left/QSPI_SD2: U1.54 (QSPI_SD2), U4.3 (IO2)
/left/QSPI_SD3: U1.51 (QSPI_SD3), U4.7 (IO3)
/left/QSPI_SS: R6.1, R7.1, U1.56 (QSPI_SS), U4.1 (~CS)
/left/RE0A: EXSW1.A, U1.7 (GPIO5)
/left/RE1A: EXSW2.A, J3.1, U1.8 (GPIO6)
/left/REB: EXSW1.B, EXSW2.B, J3.2, U1.9 (GPIO7)
/left/SWCLK: J4.1, U1.24 (SWCLK)
/left/SWD: J4.3, U1.25 (SWD)
/left/TX: J2.R, U1.15 (GPIO12)
/left/USB_VBUS_PIN: R8.2, R9.1, U1.16 (GPIO13)
/right/D+: rJ1.A6 (D+), rJ1.B6 (D+), rR4.1, rU3.1 (D1+), rU3.4 (D2+), rU3.7 (NC), rU3.10 (NC)
/right/D-: rJ1.A7 (D-), rJ1.B7 (D-), rR5.2, rU3.2 (D1-), rU3.5 (D2-), rU3.6 (NC), rU3.9 (NC)
/right/KEY1: rSW1.1, rU1.30 (GPIO19)
/right/KEY2: rSW2.1, rU1.34 (GPIO22)
/right/KEY3: rSW3.1, rU1.38 (GPIO26_ADC0)
/right/KEY4: rSW4.1, rU1.39 (GPIO27_ADC1)
/right/KEY5: rSW5.1, rU1.3 (GPIO1)
/right/KEY6: rSW6.1, rU1.40 (GPIO28_ADC2)
/right/KEY7: rSW7.1, rU1.31 (GPIO20)
/right/KEY8: rSW8.1, rU1.28 (GPIO17)
/right/KEY9: rSW9.1, rU1.27 (GPIO16)
/right/KEY10: rSW10.1, rU1.41 (GPIO29_ADC3)
/right/KEY11: rSW11.1, rU1.2 (GPIO0)
/right/KEY12: rSW12.1, rU1.4 (GPIO2)
/right/KEY13: rSW13.1, rU1.5 (GPIO3)
/right/KEY14: rSW14.1, rU1.6 (GPIO4)
/right/KEY15: rSW15.1, rU1.7 (GPIO5)
/right/KEY16: rSW16.1, rU1.29 (GPIO18)
/right/KEY17: rSW17.1, rU1.17 (GPIO14)
/right/KEY18: rSW18.1, rU1.12 (GPIO9)
/right/KEY19: rSW19.1, rU1.11 (GPIO8)
/right/KEY20: rSW20.1, rU1.14 (GPIO11)
/right/KEY21: rSW21.1, rU1.18 (GPIO15)
/right/KEYEX1: rEXSW1.S2, rU1.37 (GPIO25)
/right/KEYEX2: rEXSW2.S2, rU1.35 (GPIO23)
/right/LED: rLED1.4 (DIN), rU1.13 (GPIO10)
/right/QSPI_SCLK: rU1.52 (QSPI_SCLK), rU4.6 (CLK)
/right/QSPI_SD0: rU1.53 (QSPI_SD0), rU4.5 (DI(IO0))
/right/QSPI_SD1: rU1.55 (QSPI_SD1), rU4.2 (DO(IO1))
/right/QSPI_SD2: rU1.54 (QSPI_SD2), rU4.3 (IO2)
/right/QSPI_SD3: rU1.51 (QSPI_SD3), rU4.7 (IO3)
/right/QSPI_SS: rR6.1, rR7.1, rU1.56 (QSPI_SS), rU4.1 (~CS)
/right/RE0A: rEXSW1.A, rU1.36 (GPIO24)
/right/RE1A: rEXSW2.A, rJ3.1, rU1.8 (GPIO6)
/right/REB: rEXSW1.B, rEXSW2.B, rJ3.2, rU1.9 (GPIO7)
/right/SWCLK: rJ4.1, rU1.24 (SWCLK)
/right/SWD: rJ4.3, rU1.25 (SWD)
/right/TX: rJ2.R, rU1.15 (GPIO12)
/right/USB_VBUS_PIN: rR8.2, rR9.1, rU1.16 (GPIO13)
GND: C1.2, C2.2, C3.2, C4.2, C5.2, C6.2, C7.2, C8.2, C9.2, C10.2, C11.2, C12.2, C13.2, C14.2, C15.2, C16.2, EXLED1.3 (VSS), EXLED2.3 (VSS), EXSW1.C, EXSW1.S1, EXSW2.C, EXSW2.S1, J1.A1 (GND), J1.A12 (GND), J1.B1 (GND), J1.B12 (GND), J1.S1 (SHIELD), J2.S, J3.4, J4.2, LED1.3 (VSS), LED2.3 (VSS), LED3.3 (VSS), LED4.3 (VSS), LED5.3 (VSS), LED6.3 (VSS), LED7.3 (VSS), LED8.3 (VSS), LED9.3 (VSS), LED10.3 (VSS), LED11.3 (VSS), LED12.3 (VSS), LED13.3 (VSS), LED14.3 (VSS), LED15.3 (VSS), LED16.3 (VSS), LED17.3 (VSS), LED18.3 (VSS), LED19.3 (VSS), LED20.3 (VSS), LED21.3 (VSS), R1.1, R2.1, R9.2, SMDSW1.1, SMDSW2.1, SW1.2, SW2.2, SW3.2, SW4.2, SW5.2, SW6.2, SW7.2, SW8.2, SW9.2, SW10.2, SW11.2, SW12.2, SW13.2, SW14.2, SW15.2, SW16.2, SW17.2, SW18.2, SW19.2, SW20.2, SW21.2, U1.19 (TESTEN), U1.57 (GND), U2.1 (GND), U3.3 (GND), U3.8 (GND), U4.4 (GND), Y1.2, Y1.4
GNDR: rC1.2, rC2.2, rC3.2, rC4.2, rC5.2, rC6.2, rC7.2, rC8.2, rC9.2, rC10.2, rC11.2, rC12.2, rC13.2, rC14.2, rC15.2, rC16.2, rEXLED1.3 (VSS), rEXLED2.3 (VSS), rEXSW1.C, rEXSW1.S1, rEXSW2.C, rEXSW2.S1, rJ1.A1 (GND), rJ1.A12 (GND), rJ1.B1 (GND), rJ1.B12 (GND), rJ1.S1 (SHIELD), rJ2.S, rJ3.4, rJ4.2, rLED1.3 (VSS), rLED2.3 (VSS), rLED3.3 (VSS), rLED4.3 (VSS), rLED5.3 (VSS), rLED6.3 (VSS), rLED7.3 (VSS), rLED8.3 (VSS), rLED9.3 (VSS), rLED10.3 (VSS), rLED11.3 (VSS), rLED12.3 (VSS), rLED13.3 (VSS), rLED14.3 (VSS), rLED15.3 (VSS), rLED16.3 (VSS), rLED17.3 (VSS), rLED18.3 (VSS), rLED19.3 (VSS), rLED20.3 (VSS), rLED21.3 (VSS), rR1.1, rR2.1, rR9.2, rSMDSW1.1, rSMDSW2.1, rSW1.2, rSW2.2, rSW3.2, rSW4.2, rSW5.2, rSW6.2, rSW7.2, rSW8.2, rSW9.2, rSW10.2, rSW11.2, rSW12.2, rSW13.2, rSW14.2, rSW15.2, rSW16.2, rSW17.2, rSW18.2, rSW19.2, rSW20.2, rSW21.2, rU1.19 (TESTEN), rU1.32 (GPIO21), rU1.57 (GND), rU2.1 (GND), rU3.3 (GND), rU3.8 (GND), rU4.4 (GND), rY1.2, rY1.4
unnamed: C2.1, R3.1, Y1.3
unnamed: D1.1 (K), EXLED1.1 (VDD), EXLED2.1 (VDD), LED1.1 (VDD), LED2.1 (VDD), LED3.1 (VDD), LED4.1 (VDD), LED5.1 (VDD), LED6.1 (VDD), LED7.1 (VDD), LED8.1 (VDD), LED9.1 (VDD), LED10.1 (VDD), LED11.1 (VDD), LED12.1 (VDD), LED13.1 (VDD), LED14.1 (VDD), LED15.1 (VDD), LED16.1 (VDD), LED17.1 (VDD), LED18.1 (VDD), LED19.1 (VDD), LED20.1 (VDD), LED21.1 (VDD)
unnamed: EXLED1.4 (DIN), JP1.2 (B), LED21.2 (DOUT)
unnamed: EXLED1.2 (DOUT), EXLED2.4 (DIN)
unnamed: J1.A5 (CC1), R1.2
unnamed: J1.B5 (CC2), R2.2
unnamed: JP1.1 (A), LED18.2 (DOUT), LED19.4 (DIN)
unnamed: LED1.2 (DOUT), LED2.4 (DIN)
unnamed: LED2.2 (DOUT), LED3.4 (DIN)
unnamed: LED3.2 (DOUT), LED4.4 (DIN)
unnamed: LED4.2 (DOUT), LED5.4 (DIN)
unnamed: LED5.2 (DOUT), LED6.4 (DIN)
unnamed: LED6.2 (DOUT), LED7.4 (DIN)
unnamed: LED7.2 (DOUT), LED8.4 (DIN)
unnamed: LED8.2 (DOUT), LED9.4 (DIN)
unnamed: LED9.2 (DOUT), LED10.4 (DIN)
unnamed: LED10.2 (DOUT), LED11.4 (DIN)
unnamed: LED11.2 (DOUT), LED12.4 (DIN)
unnamed: LED12.2 (DOUT), LED13.4 (DIN)
unnamed: LED13.2 (DOUT), LED14.4 (DIN)
unnamed: LED14.2 (DOUT), LED15.4 (DIN)
unnamed: LED15.2 (DOUT), LED16.4 (DIN)
unnamed: LED16.2 (DOUT), LED17.4 (DIN)
unnamed: LED17.2 (DOUT), LED18.4 (DIN)
unnamed: LED19.2 (DOUT), LED20.4 (DIN)
unnamed: LED20.2 (DOUT), LED21.4 (DIN)
unnamed: R6.2, SMDSW1.2
unnamed: SMDSW2.2, U1.26 (RUN)
unnamed: R5.1, U1.46 (USB_DM)
unnamed: R4.2, U1.47 (USB_DP)
unnamed: C1.1, U1.20 (XIN), Y1.1
unnamed: R3.2, U1.21 (XOUT)
unnamed: rC2.1, rR3.1, rY1.3
unnamed: rD1.1 (K), rEXLED1.1 (VDD), rEXLED2.1 (VDD), rLED1.1 (VDD), rLED2.1 (VDD), rLED3.1 (VDD), rLED4.1 (VDD), rLED5.1 (VDD), rLED6.1 (VDD), rLED7.1 (VDD), rLED8.1 (VDD), rLED9.1 (VDD), rLED10.1 (VDD), rLED11.1 (VDD), rLED12.1 (VDD), rLED13.1 (VDD), rLED14.1 (VDD), rLED15.1 (VDD), rLED16.1 (VDD), rLED17.1 (VDD), rLED18.1 (VDD), rLED19.1 (VDD), rLED20.1 (VDD), rLED21.1 (VDD)
unnamed: rEXLED1.4 (DIN), rJP1.2 (B), rLED21.2 (DOUT)
unnamed: rEXLED1.2 (DOUT), rEXLED2.4 (DIN)
unnamed: rJ1.A5 (CC1), rR1.2
unnamed: rJ1.B5 (CC2), rR2.2
unnamed: rJP1.1 (A), rLED18.2 (DOUT), rLED19.4 (DIN)
unnamed: rLED1.2 (DOUT), rLED2.4 (DIN)
unnamed: rLED2.2 (DOUT), rLED3.4 (DIN)
unnamed: rLED3.2 (DOUT), rLED4.4 (DIN)
unnamed: rLED4.2 (DOUT), rLED5.4 (DIN)
unnamed: rLED5.2 (DOUT), rLED6.4 (DIN)
unnamed: rLED6.2 (DOUT), rLED7.4 (DIN)
unnamed: rLED7.2 (DOUT), rLED8.4 (DIN)
unnamed: rLED8.2 (DOUT), rLED9.4 (DIN)
unnamed: rLED9.2 (DOUT), rLED10.4 (DIN)
unnamed: rLED10.2 (DOUT), rLED11.4 (DIN)
unnamed: rLED11.2 (DOUT), rLED12.4 (DIN)
unnamed: rLED12.2 (DOUT), rLED13.4 (DIN)
unnamed: rLED13.2 (DOUT), rLED14.4 (DIN)
unnamed: rLED14.2 (DOUT), rLED15.4 (DIN)
unnamed: rLED15.2 (DOUT), rLED16.4 (DIN)
unnamed: rLED16.2 (DOUT), rLED17.4 (DIN)
unnamed: rLED17.2 (DOUT), rLED18.4 (DIN)
unnamed: rLED19.2 (DOUT), rLED20.4 (DIN)
unnamed: rLED20.2 (DOUT), rLED21.4 (DIN)
unnamed: rR6.2, rSMDSW1.2
unnamed: rSMDSW2.2, rU1.26 (RUN)
unnamed: rR5.1, rU1.46 (USB_DM)
unnamed: rR4.2, rU1.47 (USB_DP)
unnamed: rC1.1, rU1.20 (XIN), rY1.1
unnamed: rR3.2, rU1.21 (XOUT)
VBUS: J1.A4 (VBUS), J1.A9 (VBUS), J1.B4 (VBUS), J1.B9 (VBUS), R8.1, ZD1.2 (A)
VBUSR: rJ1.A4 (VBUS), rJ1.A9 (VBUS), rJ1.B4 (VBUS), rJ1.B9 (VBUS), rR8.1, rZD1.2 (A)

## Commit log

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2026-09-18 Add chalk as measured prior art: 17.000mm pitch confirmed, splayed columns, 1mm board, NC-SA license caveat
    [reversible.kicad_pcb]
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2026-09-18 Fix XIAO cutout: back-side pads face away when inverted; solve 18.0x12.6mm against castellations, cross-checked vs chalk photo
2026-09-18 Rework: topside XIAO + nice!view, battery corner cutout; measure parts from mockup photo; flag socket height and reversibility conflicts
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2026-09-18 Add pcb/sucralose.kicad_pcb: placement board with outline, 21 switches, XIAO land, jumpers; battery bay moved outboard after collision test
    [sucralose.kicad_pcb]
2026-09-18 Manually placed Xiao, display, battery.
    Manually placed and sized battery area. Rotated and placed display pins. Rotated and placed Xiao Plus location.
    [sucralose.kicad_pcb]
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2026-09-18 Rebuild outline to hug placement with rounded corners and filleted battery notch; fix regex-based s-expr deletion that corrupted the board file
    [sucralose.kicad_pcb]
2026-09-18 Updated the PCB with several changes: edge redrawn, Xaio nRF52 Plus footprint, etc.
    [sucralose.kicad_pcb]
2026-09-18 Display mount: NPTH holes with independent per-face rings; close outline
    nice!view reversible mount
    --------------------------
    A pin is soldered to the display, passed through the hole, and soldered to
    ONE face of the board. Because the board is reversible, the ring on the BACK
    must be able to carry a different net than the ring on the FRONT at the same
    hole -- so the barrel must not be plated.
    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
    [sucralose.kicad_pcb]
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2026-09-18 SW17: courtyard matches the 1.5u cap (25.5 x 16 mm)
    Every switch carried the stock 16 x 16 courtyard sized for a 1u cap. SW17 is
    the outer thumb and wears a 1.5u cap -- CAP_15U = (25.5, 16.0) in
    scripts/gen_outline.py, selected by the |rot| == 70 test that SW17 alone
    satisfies. Its courtyard therefore understated the part by 9.5 mm along the
    cap's long axis, so no collision check could see the overhang.
    F.CrtYd and B.CrtYd are now the cap extent, local X +/- 12.75, Y +/- 8.0,
    centred on the switch to match how gen_outline.py hugs it.
    Verified after the change:
    - courtyard-vs-courtyard overlaps across all 42 footprints: 0
    - SW17 courtyard fully inside the board outline, 2.974 mm to the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
    [sucralose.kicad_pcb]
2026-09-18 Place 21 reversible SOD-123 diodes, one per switch
    Position taken from chalk, not guessed
    --------------------------------------
    Measured all 21 diodes in reference/chalk/reversible.kicad_pcb against their
    own switches, transformed into the switch-local frame:
    local (0.000, -2.700), rotation offset 0
    stdev 0.0000 on X, Y and rotation across all 21
    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
    [sucralose.kicad_pcb]
2026-09-18 Fix: diode pads ignored footprint rotation
    Reported by Jahn: pads 1 and 2 of every diode stayed vertical regardless of the
    diode's rotation or the switch it sits in. Correct -- all 21 were wrong.
    Cause
    -----
    KiCad stores a pad's `(at x y angle)` as an ABSOLUTE board orientation, not an
    offset from its parent footprint. Every switch shows this: SW1 at rot 9 has all
    pads written `(at dx dy 9)`; SW17 at rot 70 has `(at dx dy 70)`. An omitted
    angle means absolute 0, not "inherit the footprint".
    The generator copied pad lines verbatim from the library footprint, which is
    authored at rot 0 and so carries no pad angle. Body, silkscreen, refdes and
    courtyard all rotated correctly, leaving the pads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
    [sucralose.kicad_pcb]
2026-09-19 Battery bay -> 25 x 37 mm, top and left edges pinned
    Requested by Jahn, who will reconcile the board edge by hand.
    Measured the old bay off the board rather than trusting the brief:
    left 177.500 top 60.321 right 198.500 bottom 103.921 = 21.005 x 43.600
    New bay, keeping left and top exactly:
    x 177.500 .. 202.500 y 60.321 .. 97.321 = 25.000 x 37.000
    Pinned-edge error is +0.0000 mm on both left and top, re-derived from the
    written file. Wider by 3.995 mm, shorter by 6.600 mm.
    The four old fillets had radii that disagreed with each other (1.17 / 1.01 /
    1.00 / 1.14) because they came out of a shapely fillet pass. Rebuilt clean at
    r = 1.0 on all four corners, cubic beziers with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
    [sucralose.kicad_pcb]
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2026-09-19 Back-side refdes silk; XIAO battery pads 28/29 to through-hole
    Silkscreen
    ----------
    Surveyed what actually renders per side first. The diode BODY outlines were
    already symmetric (147 fp_line on F.SilkS, 147 on B.SilkS) and the switches
    carry no body silk at all, so the real gap was the reference designators:
    SW<n> Reference F.SilkS 21 B.SilkS 0
    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
    [sucralose.kicad_pcb]
2026-09-19 Battery holes: unplated barrel, one pad per face, independent nets
    Corrects the plated through-hole from 93cbc64. Plated was wrong, and not
    marginally: mirroring the XIAO swaps pads 28 and 29, so each site is BAT+ for
    one mount side and BAT- for the other --
    site A (128.494, 115.982) = front pad 28 / back pad 29
    site B (126.494, 115.982) = front pad 29 / back pad 28
    A plated barrel ties the two faces together, i.e. ties BAT+ to BAT- through the
    board: a dead short across the cell. The unplated barrel is the only thing
    keeping the nets apart, exactly as with the nice!view display holes.
    Structure now, per spec:
    front XIAO footprint : SMD pad on F.Cu + bare np_thru_hole barrel (0.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
    [sucralose.kicad_pcb]
2026-09-19 Display holes: front owns hole + pad, back is pad-only
    Applies the battery-hole structure to the display stack.
    Before, each nice_view footprint carried 15 pads -- 5 bare barrels, 5 pads on
    F.Cu and 5 on B.Cu -- so BOTH footprints emitted coincident NPTH and every
    display site was drilled twice, with each footprint also placing copper on the
    far face.
    Now:
    front nice_view : 5 smd pads on F.Cu + 5 bare np_thru_hole barrels
    back nice_view : 5 smd pads on B.Cu (no holes)
    Each footprint keeps only its own-face pads. Pads renumbered 1-5 by local X to
    match the nice_view symbol: 1 MOSI, 2 SCK, 3 VCC, 4 GND, 5 CS.
    Reversal is unchanged and still comes from the placement (front ro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
    [sucralose.kicad_pcb]
2026-09-19 Netlist: 38 nets, matrix derived from geometry, no schematic
    This board has no schematic and never had one. Neither does reference/chalk,
    which carries 80 nets and 866 tracks with no .kicad_sch anywhere -- nets live
    in the .kicad_pcb, and a schematic is only the usual authoring tool for them.
    Matrix derived from placement, not transcribed
    ----------------------------------------------
    Columns are splayed, so a column is not "same X". Two keys share a column when
    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
    [sucralose.kicad_pcb]
2026-09-19 Bind COL/ROW/display nets to XIAO Plus pins
    ZMK has no board definition for the Plus, only seeed/xiao_ble for the standard
    XIAO nRF52840. The Plus keeps the standard 14-pin layout and adds nine
    castellated pins, so the mapping was resolved from primary sources rather than
    the wiki pinout image, which is disputed.
    Evidence, two independent chains agreeing on every pin used:
    Zephyr boards/seeed/xiao_ble/seeed_xiao_connector.dtsi gives the xiao_d
    nexus, D0..D10 = P0.02 P0.03 P0.28 P0.29 P0.04 P0.05 P1.11 P1.12 P1.13
    P1.14 P1.15. ZMK inherits this nexus.
    Seeed's own symbol library maps footprint pad -> pin name: pads 1..11 =
    D0..D10, 12=3V3, 13=GND, 14=VBUS, pads 15..23 = D11..D19.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
    [sucralose.kicad_pcb]
2026-09-19 Netlist for a front-mounted build: hole nets through front jumpers
    Jahn caught two real problems: BAT_P and GND appeared shorted, and nothing
    connected to the display or battery solder jumpers.
    Nothing was shorted in copper. The barrels are unplated, no site+face carried
    two nets, and DRC reported no shorts. What showed was the ratsnest: both XIAO
    footprints were netted, so BAT_P sat on the front footprint's pad 28 AND the
    back footprint's pad 28, which land on OPPOSITE physical holes. That told KiCad
    one net had to reach both sites, and its airwire crossed GND's, drawing an X
    over the battery pads. The netlist was wrong even though the copper was not.
    The jumpers were placed as geometry o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
    [sucralose.kicad_pcb]
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2026-09-19 Route all 43 nets: 506 segments, 86 vias, zero copper errors
    Scripted grid A* router (scripts/route/). No autorouter exists in the
    container: kicad-cli has no DSN export and there is no Java.
    Routed on 0.25 mm grid, 0.25 mm track, 0.3 mm clearance (netclass 0.2),
    0.6/0.3 vias. Rows prefer B.Cu, columns F.Cu. Every net reached every
    site: 0 router failures.
    DRC after routing:
    shorting_items 0
    clearance 0
    hole_clearance 0
    track_dangling 0
    unconnected_items 20 (was 138)
    everything else unchanged at the 88 pre-routing baseline
    Three bugs fixed on the way, each caught by kicad-cli DRC not by the router:
    * snapping a segment endpoint to the pad centre dra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
    [sucralose.kicad_pcb]
2026-09-19 Netlist for both builds; strip copper pending jumper-strip respacing
    The back XIAO's signal pads (1-13, 15, 16) and the back JST are real
    terminals for the reverse build, not dead copper. Net them:
    back XIAO pad N = front XIAO pad N (same GPIO), 15 pads
    back JST 1=GND 2=BAT_P (mirror of front 1=BAT_P 2=GND)
    Battery lands 28/29 stay per-hole and swap on mirror, as before.
    Copper removed. The front-only route in 2b59dac was built on the wrong
    model (back lands as obstacles). Routing both builds against the
    current geometry fails on 3 nets after rip-up: every signal must reach
    both mirrored XIAO pad rows through the same ~13 mm of edge, and the
    jumper strip at y=53.5 has ~5 mm pitch with n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
    [sucralose.kicad_pcb]
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2026-09-19 Route both builds: 42 of 43 nets, copper DRC clean
    622 segments, 118 vias. DRC = 88, identical to the unrouted baseline:
    0 shorting_items, 0 clearance, 0 tracks_crossing, 0 hole_clearance.
    Unconnected 155 -> 8: 7 are the display/battery ring pairs (front pad
    and back pad of one NPTH; the soldered pin is the joint, KiCad cannot
    model it) and 1 is MOSI, unrouted between the front XIAO pad 11 and
    the jumper strip after 5 rip-up rounds. Every other signal reaches
    both mirrored XIAO rows.
    Router fixes since 1c64a1d:
    * via halo was double-counting clearance (1.0 mm to pad edge vs 0.55
    legal); that alone walled off XIAO pads 15/16. Now VIA_D/2-TRACK/2
    plus a 0.25 mm end-cap margin, vias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
    [sucralose.kicad_pcb]
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2026-09-19 Fully routed, both builds: 43/43 nets, DRC 88 (= unrouted baseline)
    MOSI moved D10 -> D4 (P0.04, fast pin per nRF52840 PS); COL4 -> D10.
    All three display lines now on spec-rated pins. docs/PINOUT.md carries
    the new table, kscan block, and a spi3 pinctrl for the display.
    640 segments, 127 vias, 0 shorts / clearance / crossing / hole hits.
    Unconnected 7 = the five display and two battery ring pairs (front and
    back pad of one NPTH; the soldered pin joins them).
    Router: search cap was 400k expansions, set for the 0.25 grid and never
    rescaled at 0.125; it was aborting long nets mid-board and reporting
    them unroutable. Lifted to 3M: SCK routed first pass. Orthogonal turns
    now require the outer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
    [sucralose.kicad_pcb]
2026-09-19 Silk: switch labels C<col> R<row> both faces; Splenda packet logo front+back (traced, 11.5 mm, top-left)
    Labels derived from netlist (switch pad -> COL, key net -> diode -> ROW), not hand-typed.
    Logo: potracer + shapely, holes stitched into single-ring gr_poly; verified in the
    F.SilkS/B.SilkS SVG export (back mirrored, reads correctly). Copper untouched: DRC 88,
    7 unconnected = ring pairs, audit 0. scripts/silk_*.py regenerate both.
    [sucralose.kicad_pcb]
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2026-09-19 Dwgs.User: battery bay label now reads 25x38.5mm, recentred on the lengthened cutout
    [sucralose.kicad_pcb]
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2026-09-29 Power switch (option A): Alps SSSS811101 side slide on edge below battery cutout; JST+ -> BAT_RAW, switch in series to BAT_P; reversible F/B copies; no HW reset (XIAO button + ZMK)
    [sucralose.kicad_pcb]
2026-09-29 EXPERIMENT: Splenda logo scaled 11.5 -> 84 mm tall, centred (122,94), front+back, to preview silk interference. Not for fab.
    [sucralose.kicad_pcb]
2026-09-29 EXPERIMENT: big Splenda logo shifted +26 mm toward battery cutout, centre (148,94). Not for fab.
    [sucralose.kicad_pcb]
2026-09-29 EXPERIMENT: back-silk Splenda logo = front geometry (left half is a true mirror of the right: packet by the battery cutout, granules onto the XIAO; wordmark reads mirrored). Not for fab.
    [sucralose.kicad_pcb]
2026-09-29 EXPERIMENT: fix side error. Back (right half) restored to 7622c74; front (left half, cutout on its right) now carries the flipped art so both halves mirror. Not for fab.
    [sucralose.kicad_pcb]
2026-09-30 Optional RST button: reversible B3U-1000P lands at (144.65,130.15) beside the XIAO toward C5; XIAO pad 26 (EN=/RESET) netted RST, routed both faces; audit expects RST on 26. DRC unchanged vs parent.
    [sucralose.kicad_pcb]
2026-09-30 RST: plated through-hole on XIAO pad 26 (both copies) + per-face RST solder jumper at (139.8,127.8), mirroring battery-pad scheme (RSTH_A/RSTH_B site nets). Button ref RST->RESET. B GND bus nudged to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
    [sucralose.kicad_pcb]
2026-09-30 RESET button +0.4 mm toward bottom edge (144.65,130.55): side-push B3U-3000P plunger now ~0.65 mm past edge. Pads 0.52 mm from edge. DRC: +2 silk_edge warnings only.
    [sucralose.kicad_pcb]
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2026-10-01 Fix back-side JST polarity: B.Cu Bat JST pad1=BAT_RAW, pad2=GND (matches front). Rerouted B.Cu GND/BAT_RAW stubs, F.Cu GND via moved to (190.57,99.85). DRC: violation categories and unconnected list 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
    [sucralose.kicad_pcb]
2026-10-01 JST polarity flipped on both faces to match common Amazon PH2.0 LiPo leads: pad1=GND, pad2=BAT_RAW (F and B). Rerouted stubs; GND via unchanged at (190.57,99.85). DRC: categories and unconnected list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
    [sucralose.kicad_pcb]
2026-10-01 Silk: +/- polarity marks beside Bat JST on F.SilkS and B.SilkS (1.5 mm, B mirrored). DRC categories unchanged.
    [sucralose.kicad_pcb]
2026-10-01 Revert "JST polarity flipped on both faces to match common Amazon PH2.0 LiPo leads: pad1=GND, pad2=BAT_RAW (F and B). Rerouted stubs; GND via unchanged at (190.57,99.85). DRC: categories and unconnec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
    This reverts commit fbd6f0a4bc14a2cd66f792ec3673c71804698fd7.
    [sucralose.kicad_pcb]
2026-10-01 JST: + on left (pad1=BAT_RAW) viewed from each face; reverts fbd6f0a polarity, silk +/- swapped to match. DRC categories unchanged.
    [sucralose.kicad_pcb]
2026-10-02 Switch PTHs (SW1-21 pads 1/2): drill 0.8 -> 1.0 mm for better solder wicking; pad 1.5x2 oval unchanged (min annular 0.25). DRC categories identical.
    [sucralose.kicad_pcb]
2026-10-03 Switch locating-pin NPTHs: 4 per switch (1.2 mm at y-2.75, 1.0 mm at y+2.75, x+-5.8, per marbastlib PG1316S) on SW1-21 + lib footprint; 1.0 mm PTH legs kept. Rerouted 47 track/via items that hit the 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
    [sucralose.kicad_pcb]
2026-10-04 Case: partial covers (battery top/bottom, XIAO, nice!view) as STEP, generated from the board file by scripts/case/gen_partial_covers.py; L and mirrored R; left assembly with PCB
    [sucralose-pcb.step, sucralose_battery_bottom_L.step, sucralose_battery_bottom_R.step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]
2026-10-04 Case: L/R reference DXFs (outline, bay, keycaps, 0.5 mm guards, M1 holes, cover outlines sectioned from STEP), same frame as STEP
    [sucralose_reference_L.dxf, sucralose_reference_R.dxf]
2026-10-04 Reference DXFs: add XIAO body outline (User.1, 17.78 x 20.95) and USB-C shell on layers XIAO / XIAO_USB
    [sucralose_reference_L.dxf, sucralose_reference_R.dxf]
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2026-10-05 Add ZMK module for the Sucralose shield
    Builds as seeeduino_xiao_ble (the Sense board's defaults collide with
    Sucralose's pins). The nice!view moves to SPIM3 so TWIM0 stays free for
    the onboard IMU. PINOUT corrected: display CS is active high.
2026-10-06 Case: replace pre-final covers with final STLs (battery cover/plate, L/R XIAO, L screen) and reference DXFs
    [Sucralose L Battery Cover Rev 1.stl, Sucralose L Battery Plate Rev 1.stl, Sucralose L Screen Cover Rev 8.stl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]
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2026-10-07 pinky-col7: breakaway 7th column, 3x PG1316M portrait (C6 R0-R2, D22-24) beside COL0, rows aligned to COL0. Strip joined by 4 mouse-bite tabs (0.6 mm NPTH, 0.35 mm web); 1.0 mm slots with main-side w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
    [sucralose.kicad_pcb]
2026-10-07 pinky-col7: 4th key (C6 R3, top, next to display; matrix slot ROW3/COL6, D22). Strip now spans the main board's full height (top/bottom edges flush with COL0 section) with its outer corners copying t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
    [sucralose.kicad_pcb]
2026-10-08 battery-edge: right edge x 203.5 -> 204.9, straight from the top corner down to the switch-corner peak (old notch/bulge at y107-112 removed, now one slight angle). PWR switch F/B moved +1.4 mm so the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
    [sucralose.kicad_pcb]
2026-10-08 battery-edge: right edge +1.5 more (x 206.4). Battery cutout +1.5 right (x 178.5-203.5) and bottom +0.75 (y 59.5-98.75, 25.0 x 39.25). 3x M1 left of cutout at x 177.075 (y 68.5/78.75/89.0), right-sid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
    [sucralose.kicad_pcb]
2026-10-08 M1 holes: courtyard dia 2.6 -> 2.2 mm and head outline (Cmts.User) 2.4 -> 2.2 mm, 0.05 stroke, on all 16. Basis: ISO 7045 / JIS B 1111 M1.2 pan head dk max 2.0 (Nitto Seiko table), 0.1 mm margin. Dri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
    [sucralose.kicad_pcb]
2026-10-08 battery-edge: right edge pulled in 206.4 -> 205.35 using the 2.2 mm M1 courtyards. Cutout x 177.95-202.95, y 59.5-98.5 (25.0 x 39.0). Left M1 trio x 176.75 (courtyard abuts C5 courtyard at 175.65), r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
    [sucralose.kicad_pcb]
2026-10-08 battery-edge: JST F/B +3.0 mm toward the edge (x ~191.6), clearing C5 R3; cutout bottom 98.5 -> 99.65 (25.0 x 40.15). Bottom-right battery M1 -> (199.45, 101.15) to sit between JST and PWR; its silk 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
    [sucralose.kicad_pcb]
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2026-10-08 Display M1 hole moved to 5.0 mm (c-c) below the last nice!view pad, on the header line: (102.8825, 73.374). ROW0 B.Cu diagonal that crossed it rerouted (45-H-45 dogleg, 0.35+ mm clearance). DRC count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
    [sucralose.kicad_pcb]
2026-10-09 Display M1 hole moved to 3.5 mm (c-c) below the last nice!view pad, on the header line: (102.648, 71.892). ROW0 B.Cu diagonal rerouted as 45-H-45 above the hole (clearance >=0.53 mm). DRC count uncha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
    [sucralose.kicad_pcb]
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2026-10-09 Front silk Splenda wordmark: mirror across packet short axis so it reads correctly from the front; recentred on original span along packet. Back silk untouched. DRC 376 (silk_overlap +14: wordmark no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
    [sucralose.kicad_pcb]
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2026-10-21 Case: revert L paste jig Rev.1 to 1.00 mm pocket (deeper pocket was for main only).
2026-10-21 Case: paste jigs main -> Rev.2. L and R both 1.10 mm pocket (plate 4.10 mm). 'Sucralose Rev. 2' debossed 0.6 mm, DejaVu Sans Bold 6 mm, centred in bottom border; applied after mirroring so R reads co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
2026-10-31 Firmware: add breakaway COL6 on both halves (14 columns, 50 keys). COL6 = &gpio1 1 (D13/P1.01), outermost on each half; right col-offset 7. Strip keys: media/PSCRN/INS/DEL/CAPS on base, F1-F12 on low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
2026-11-02 Case: add Sucralose2 covers (L Battery Plate Rev1, L Screen Cover Rev1, L/R Xiao Cover Rev 3 STL) and L/R Reference Rev.2 DXF. Keymap: align comment diagrams (no binding changes).
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2026-11-12 Rev3 RGB WIP: 21 WS2812B-2020 + SOD-523 placed under every PG1316S, LED power gate, COL5 -> D14.
    Board: SOD-123 main diodes replaced by SOD-523 (same refs/nets) in the switch pocket; L1-L21 chained LD0 (XIAO D5) ... LD20, C3R3 first. Gate per face: AO3401A PMOS 3V3->VLED, 100k pull-up, 10uF; gate LED_EN = D15 (P0.10). COL5 moved to D14 (P0.09).
    Routing: scripted grid A*. DRC: 24 real unconnected left (GND x9, VLED x4, LED_EN x5, COL5, CS, ROW1, ROW2, DISP_H1/H2 stubs) + the 5 by-design display rings. NOT fab-ready.
    Firmware: ws2812-spi on SPIM2/D5 (21 LEDs), ext-power on D15, uicr nfct-pins-as-gpios, COL5 on gpio0 9; brightness max 40. Both halves build on ZMK v0.3.
2026-11-12 Rev3 RGB routing: LED twins joined first with a 4.5 mm escape, then LED chain/VLED/long nets, then the rest.
    LED data chain LD0-LD20 and VLED fully connected. DRC: 17 real unconnected (LED_EN x5, GND twin x3, VCC x2, middle_bottom x2, COL5, COL6, BAT_P, DISP_H1, DISP_H2) + 5 by-design display rings; 0 shorts, 0 clearance. ~94 dangling stubs remain (harmless).
2026-11-12 Rev3 RGB: LED power gate (Q/R/C both faces) moved to 180.75,104.0 beside BYP, out of the XIAO congestion; VCC and VLED now complete.
    DRC: 14 real unconnected (LED_EN x3: XIAO pad 19 F/B and to gate; GND twin x4 (L10, L12, L15, one stub); COL5 F-B; COL6 strip; DISP_H1; DISP_H2; BAT_P; middle_bottom x2) + 5 by-design display rings. 0 shorts, 0 clearance.
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2026-11-14 Rev3 RGB: DISP_H1 tracks moved 0.02 mm off the display NPTH drill edge (hole_clearance 2->0); trimmed GND (via->L2.2) and ROW2 (D1.1) track overshoots (track_dangling 2->0). Unconnected = only the 5 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
2026-11-14 Silk: wordmark 'Splenda' -> 'Spenda' on both faces. 'l' polygon deleted; 'enda' + (R) slid 2.933 mm back along the wordmark axis so p-e spacing = existing letter spacing (0.513 mm). 'Sp' fixed (movin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

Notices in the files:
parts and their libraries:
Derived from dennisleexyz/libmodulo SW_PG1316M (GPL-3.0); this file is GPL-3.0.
